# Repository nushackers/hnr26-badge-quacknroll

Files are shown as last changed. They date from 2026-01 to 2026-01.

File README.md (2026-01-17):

# hack&Roll 2026 "Quack & Roll" hardware badge

This repository contains both the hardware and firmware source files for the
Hack&Roll 2026 hardware badge.

## License

See the root directory's [LICENSE.md](./LICENSE.md) for more information on how
these materials are licensed.

## Acknowledgements

This Hack&Roll 2026 hardware badge would not have been possible without the
following people:

- **Terence** Chan Zun Mun ([@Hackin7](https://github.com/Hackin7)), for his
  invaluable knowledge and guidance in PCB design and hardware badge
  development, as well as liaising with Espressif Systems
- Lim **Yik Jin** ([@yikjin](https://github.com/yikjin)), for developing the
  hardware badge
- Park **Youngseo** ([@youngseopark05](https://github.com/youngseopark05)), for
  creating the artwork used for this hardware badge
- Koh Chan Hong, **Ravern** ([@ravern](https://github.com/ravern)), for liaising
  with Espressif Systems
- Tan Rongwen, **Daren** ([@darentanrw](https://github.com/darentanrw)), for
  liaising with Espressif Systems
- Everyone in [NUS Hackers](https://www.nushackers.org/) for making Hack&Roll
  2026 a reality!

The ESP32-C3-WROOM-02-N4 module in this hardware badge is also sponsored by
[Espressif Systems](https://www.espressif.com/), the manufacturers of the
widely-used ESP32 chips.

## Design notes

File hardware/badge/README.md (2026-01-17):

# HnR'26 hardware badge: hardware source files

This directory contains the [KiCad](https://www.kicad.org/) 9 hardware source
files for the Hack&Roll 2026 hardware badge.

## Manufacturing

We used [JLCPCB manufacturing services](https://jlcpcb.com/) for the hardware
badges. To help with component parts assignment and generating JLCPCB-compatible
files, we used the open source
[KiCAD JLCPCB tools](https://github.com/bouni/kicad-jlcpcb-tools) plugin.

## License

The hardware source files in this directory are open-sourced, licensed under
CERN-OHL-P-2.0. See [LICENSE.md](./LICENSE.md) for the full license text.

## Acknowledgements

HnR'26 hardware badge would not have been possible without the following people:

- **Terence** Chan Zun Mun ([@Hackin7](https://github.com/Hackin7)), for his
  invaluable knowledge and guidance in PCB design and hardware badge
  development, as well as liaising with Espressif Systems
- Lim **Yik Jin** ([@yikjin](https://github.com/yikjin)), for developing the
  hardware badge
- Park **Youngseo** ([@youngseopark05](https://github.com/youngseopark05)), for
  creating the artwork used for this hardware badge, and for HnR'26 in general
- **Daren** Tan Rongwen ([@darentanrw](https://github.com/darentanrw)), for
  liaising with Espressif Systems

The ESP32-C3-WROOM-02-N4 module in this hardware badge is also sponsored by
[Espressif Systems](https://www.espressif.com/), the manufacturers of the
widely-used ESP32 chips.

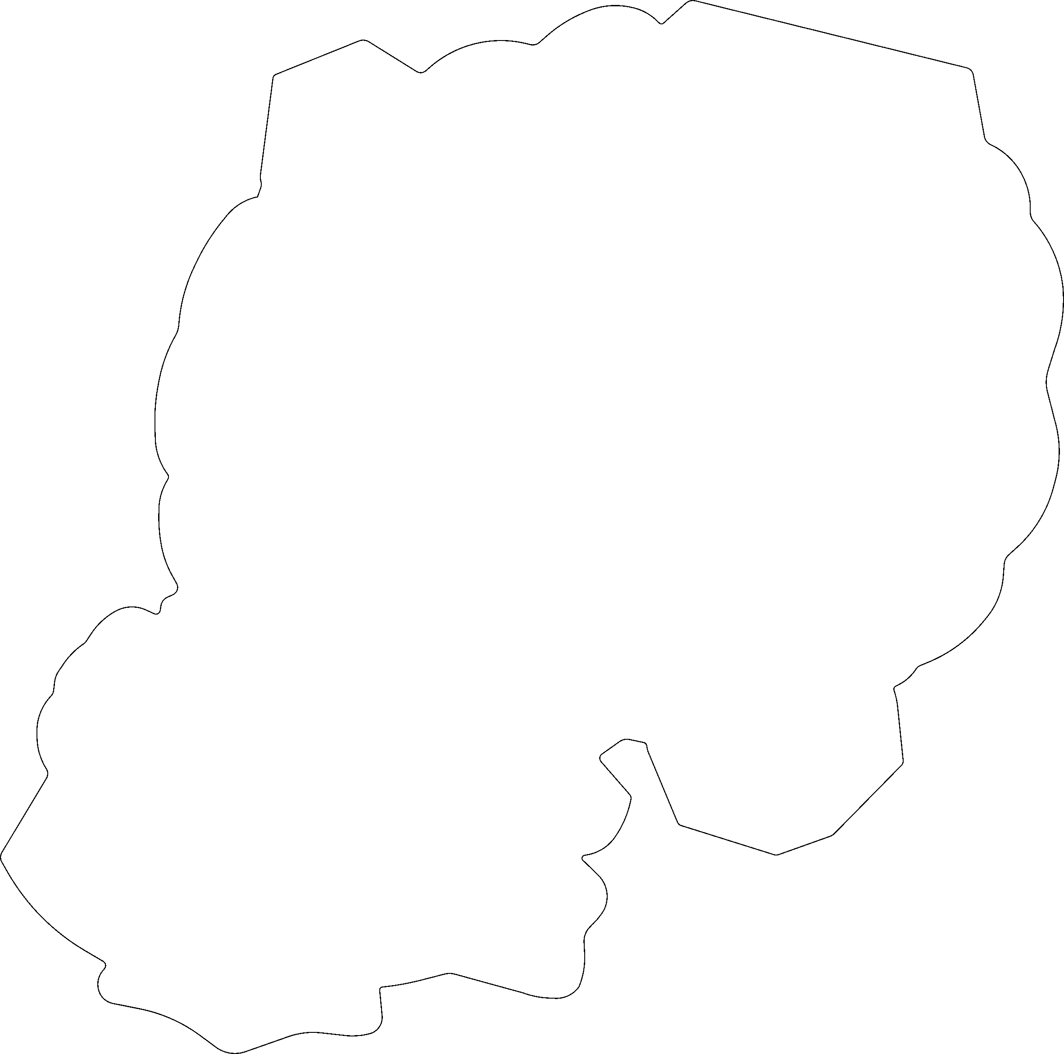
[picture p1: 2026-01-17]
art/outline.png

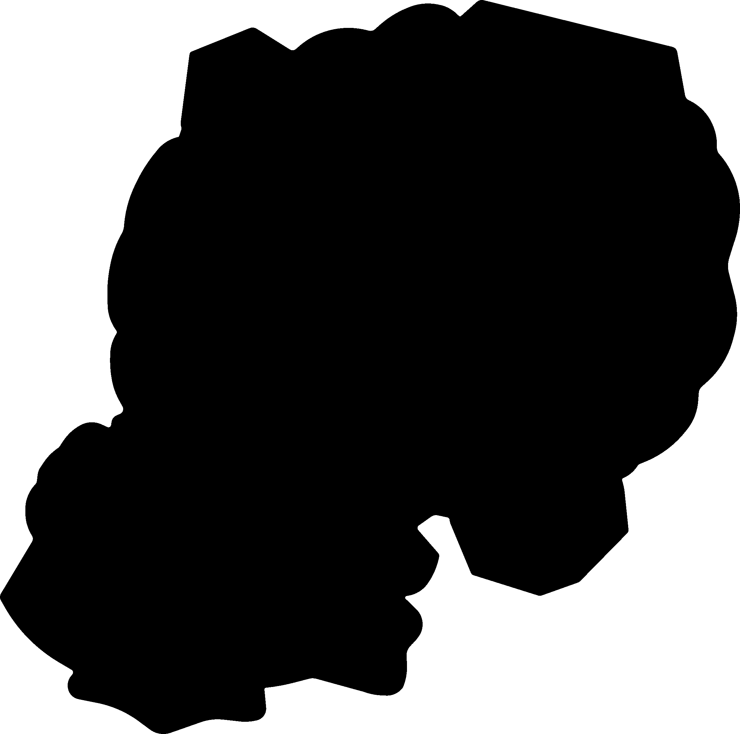
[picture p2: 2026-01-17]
art/board.png

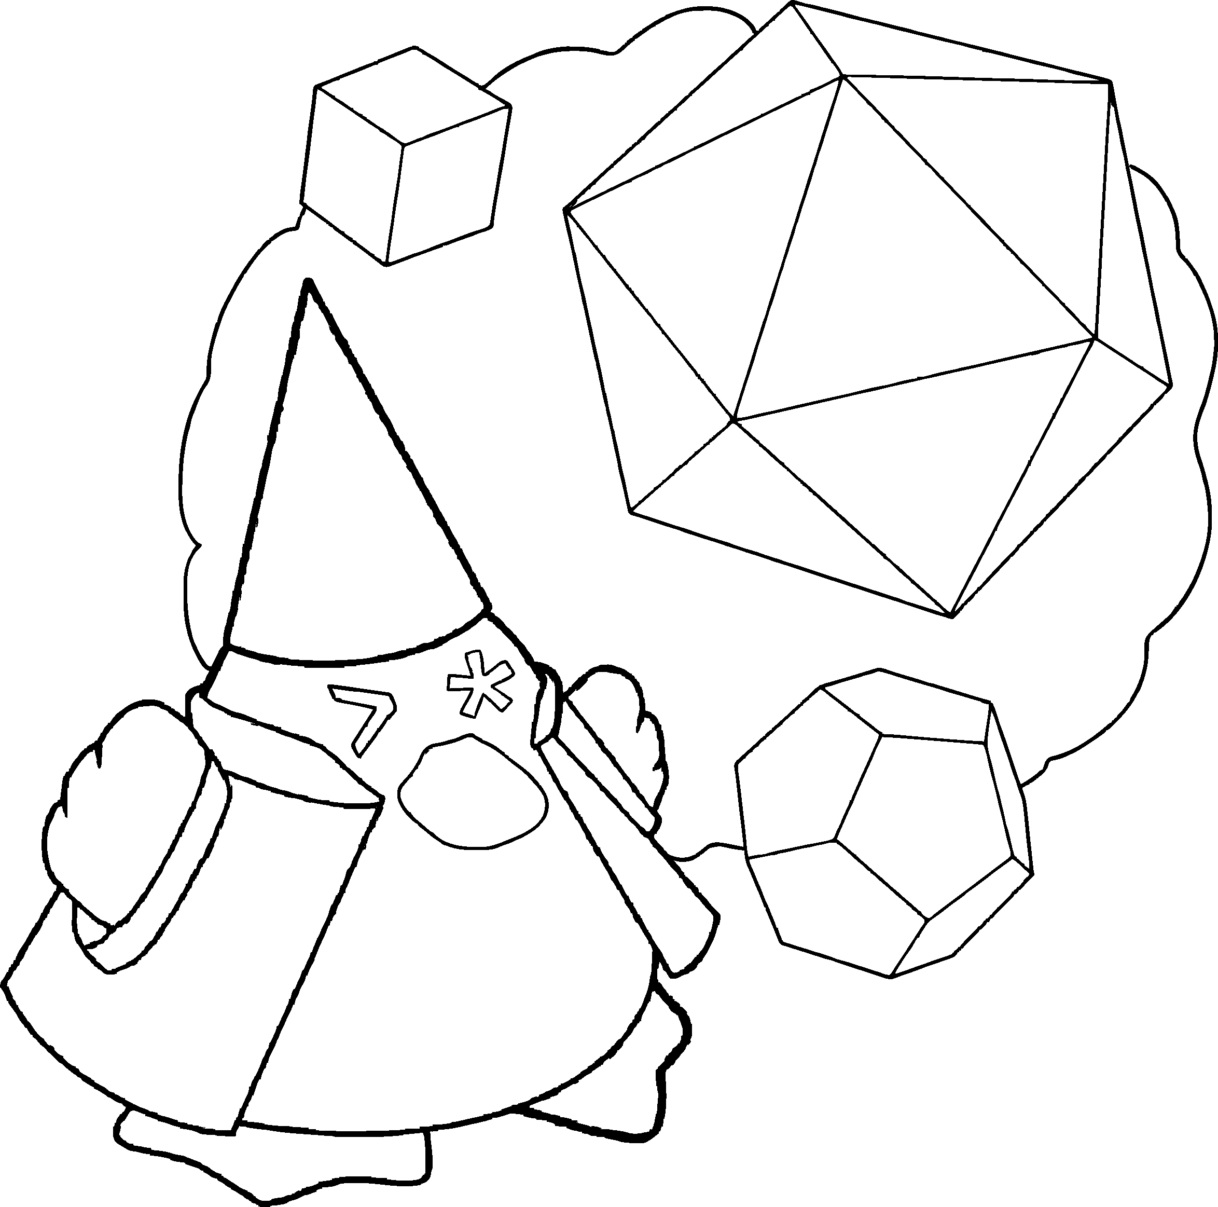
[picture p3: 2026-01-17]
art/art.png

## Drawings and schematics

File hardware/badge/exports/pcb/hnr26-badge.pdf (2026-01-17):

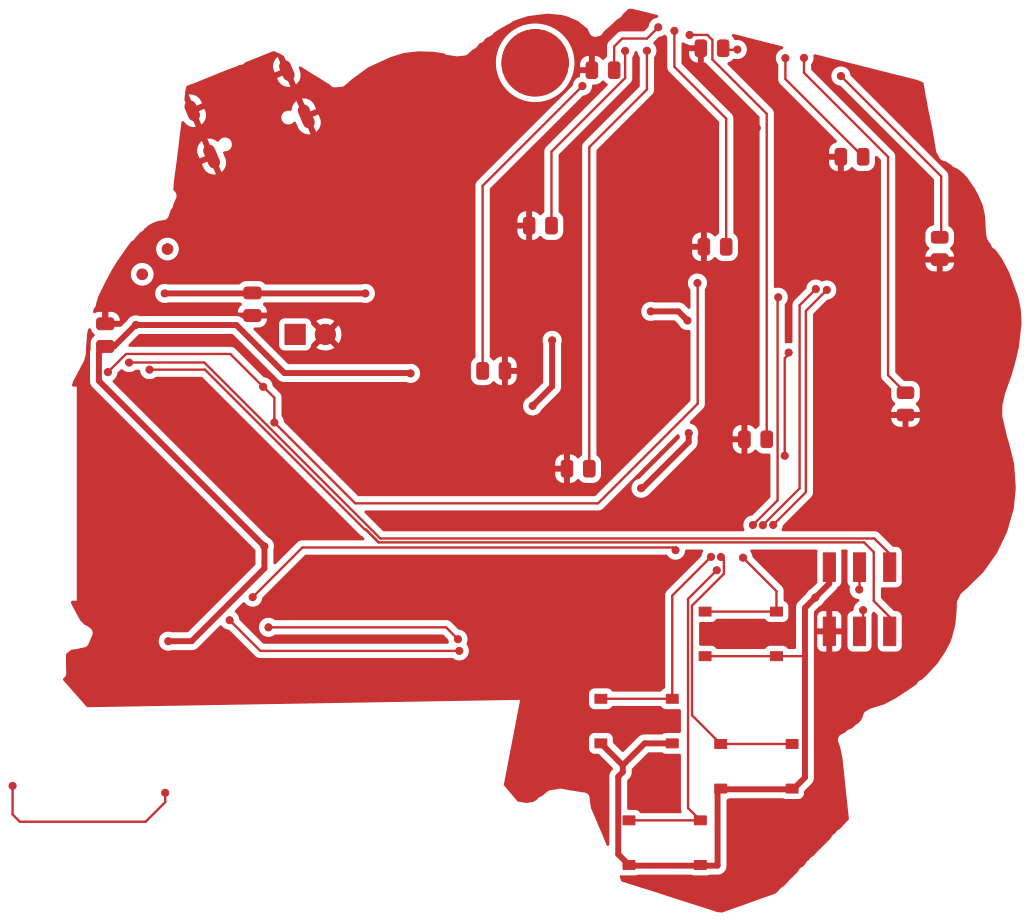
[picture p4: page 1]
D Date: 2025-12-01 KiCad; E.D.A. 9.0.7 Size: A4; Rev: 0.0.14; File: hnr26-badge.kicad_pcb Sheet: NUS; Hackers Art by @youngseopark05; Developed; by @yikjin and; @Hackin7; Licensed; under CERN-OHL-P-2.0

Id: 1/9 Title: Hack&Roll 2026 hardware badge

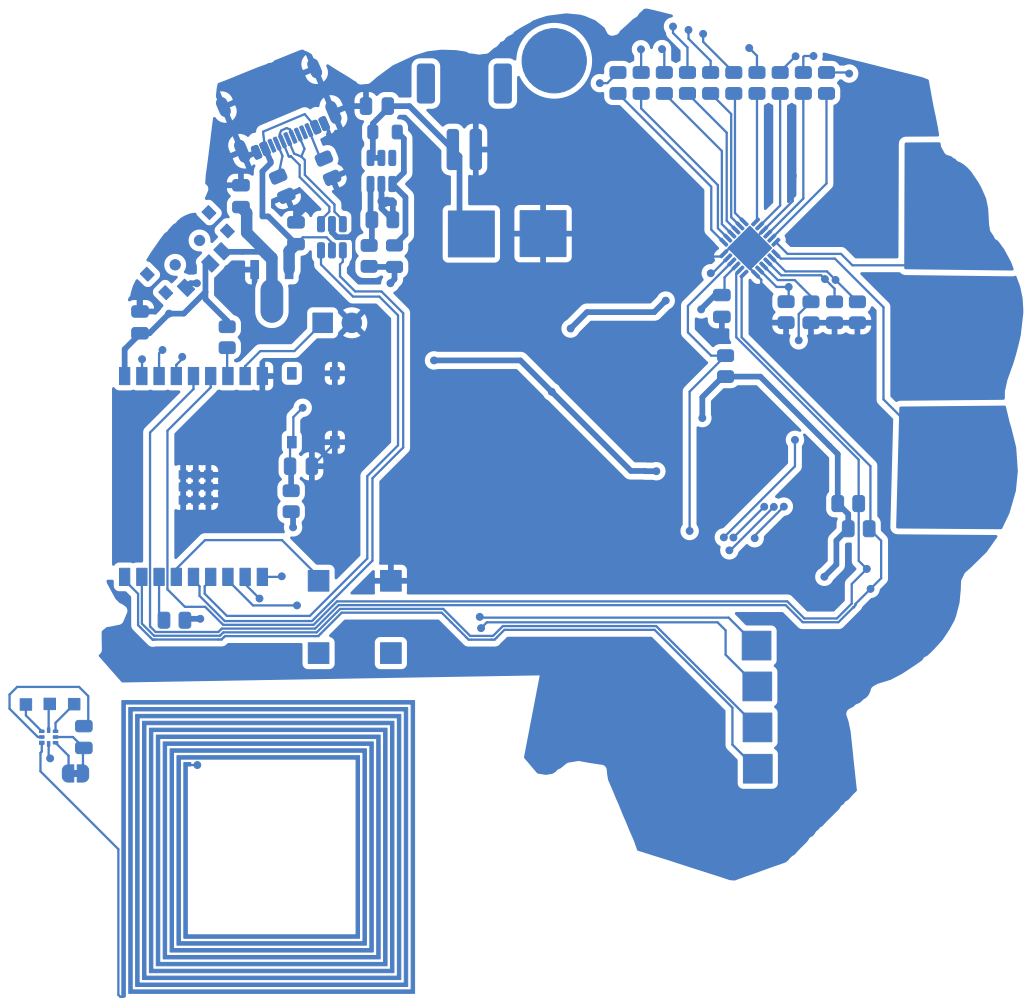
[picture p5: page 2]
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

Id: 2/9 Title: Hack&Roll 2026 hardware badge

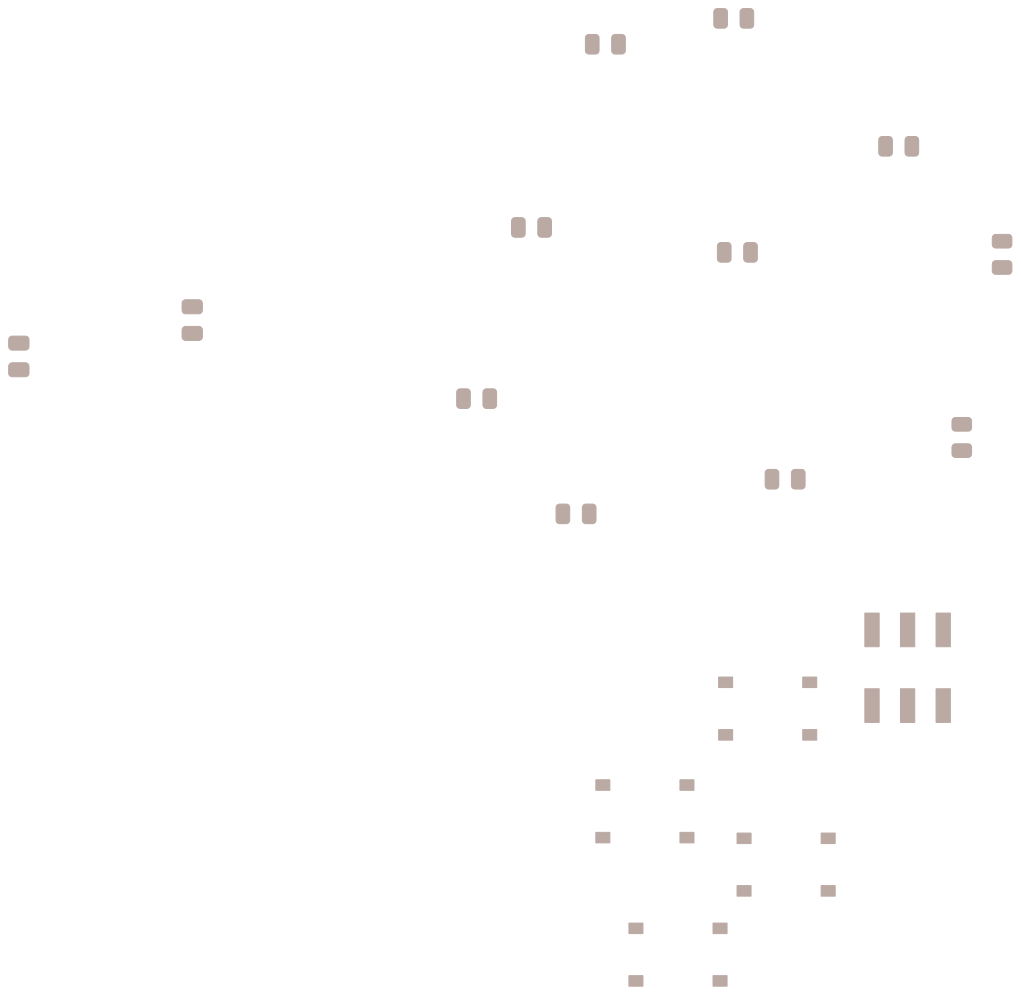
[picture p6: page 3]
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

Id: 3/9 Title: Hack&Roll 2026 hardware badge

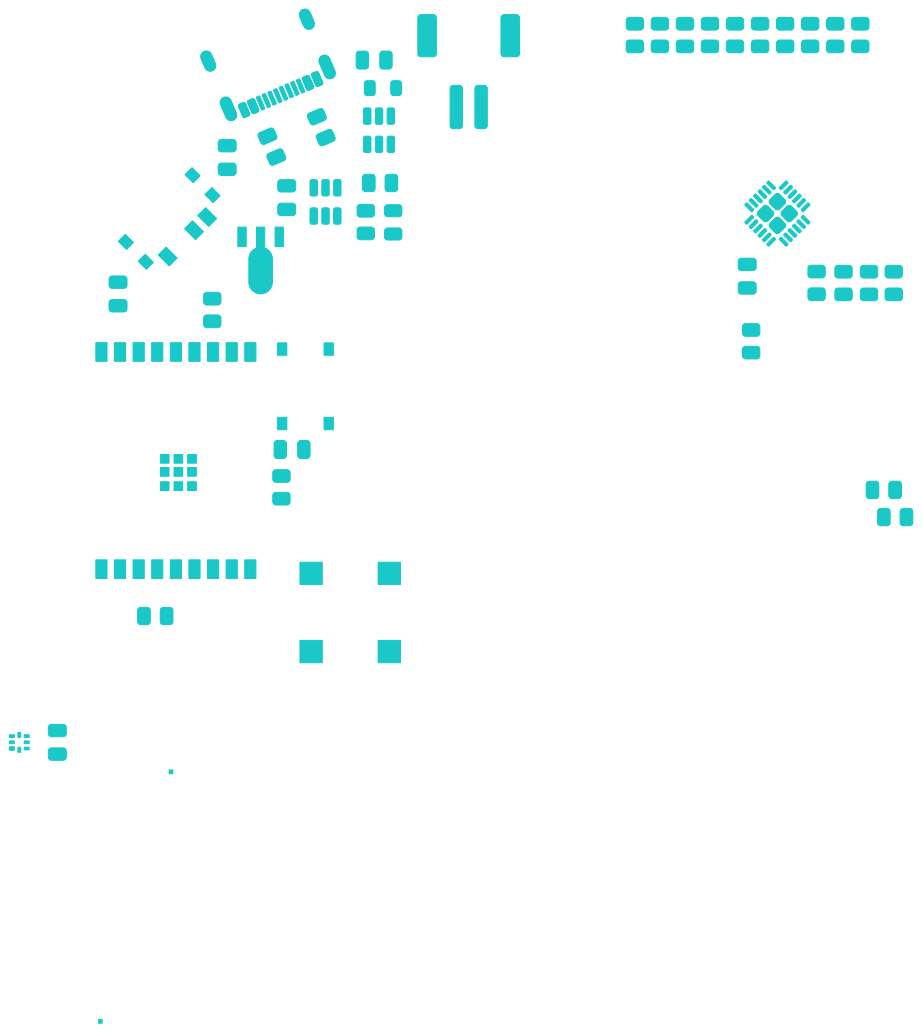
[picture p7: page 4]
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

Id: 4/9 Title: Hack&Roll 2026 hardware badge

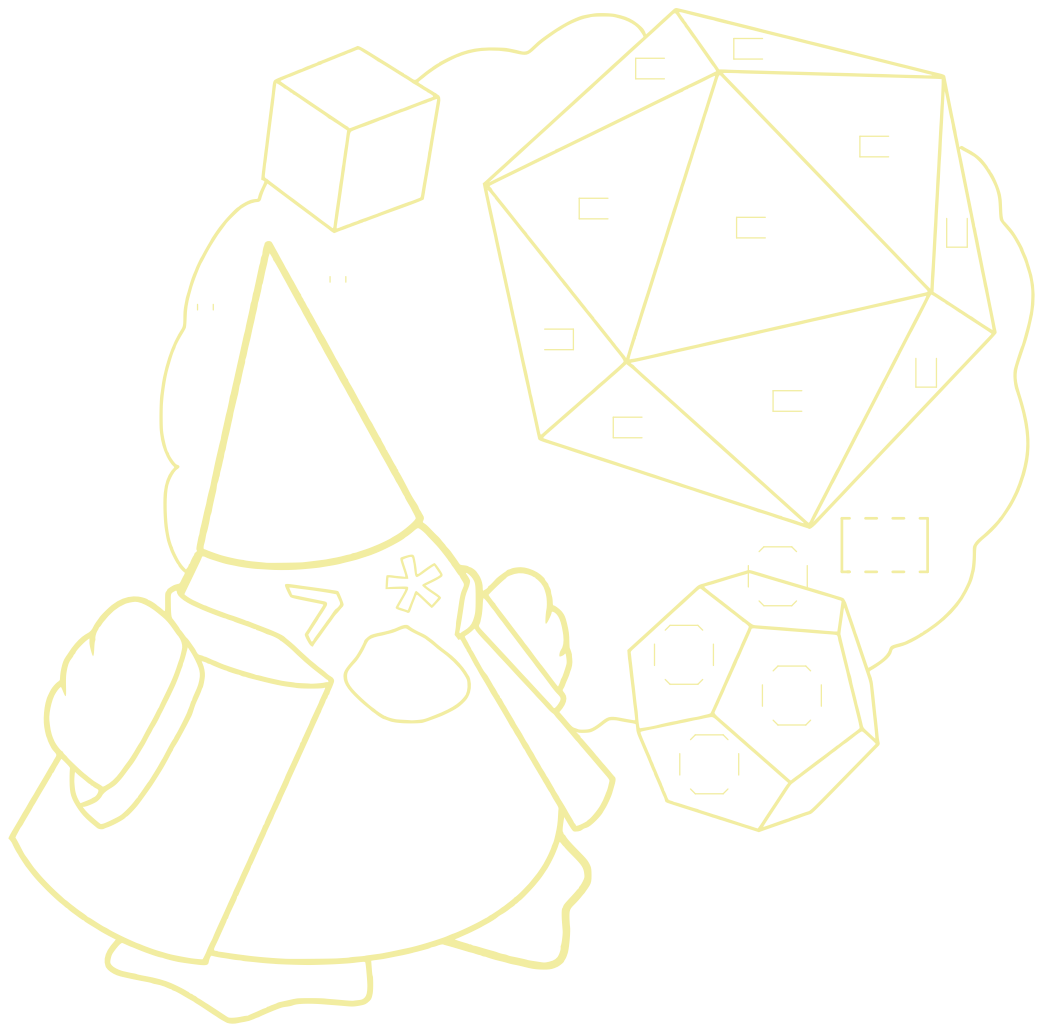
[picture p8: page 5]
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

Id: 5/9 Title: Hack&Roll 2026 hardware badge

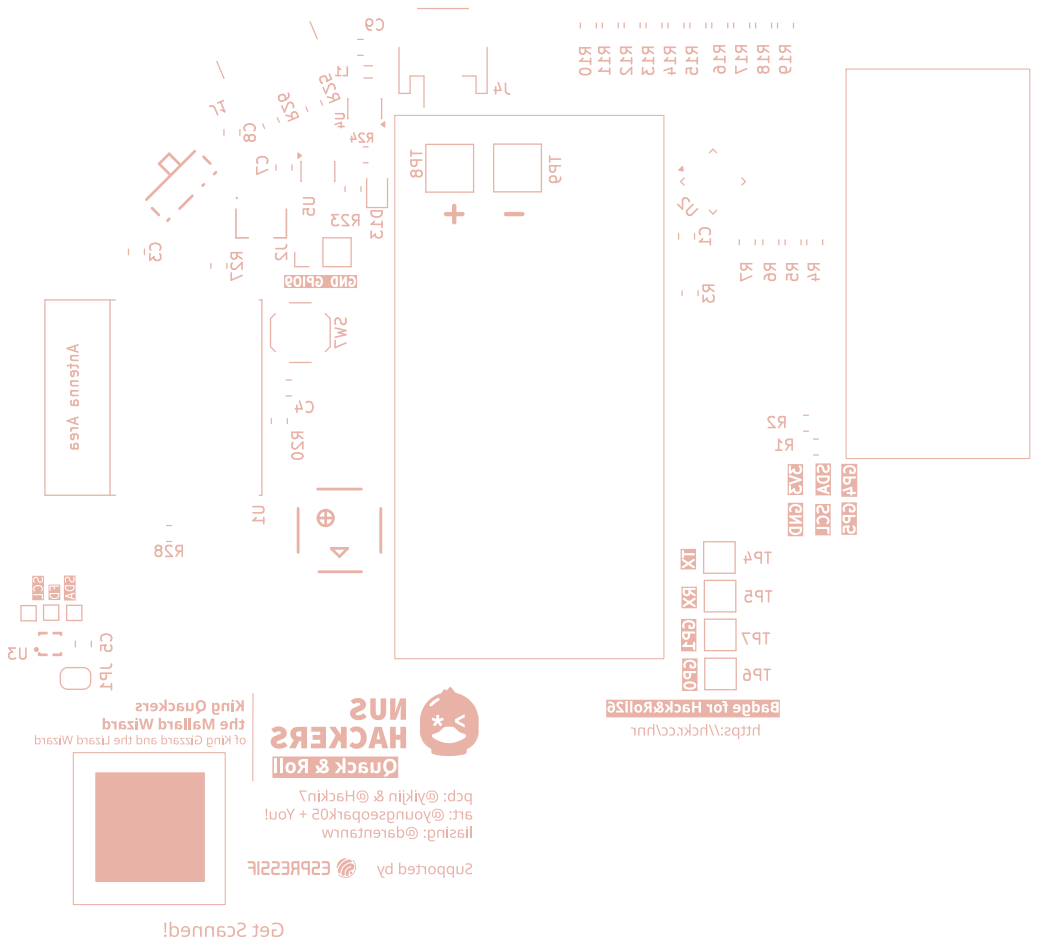
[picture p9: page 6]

Id: 6/9 Title: Hack&Roll 2026 hardware badge

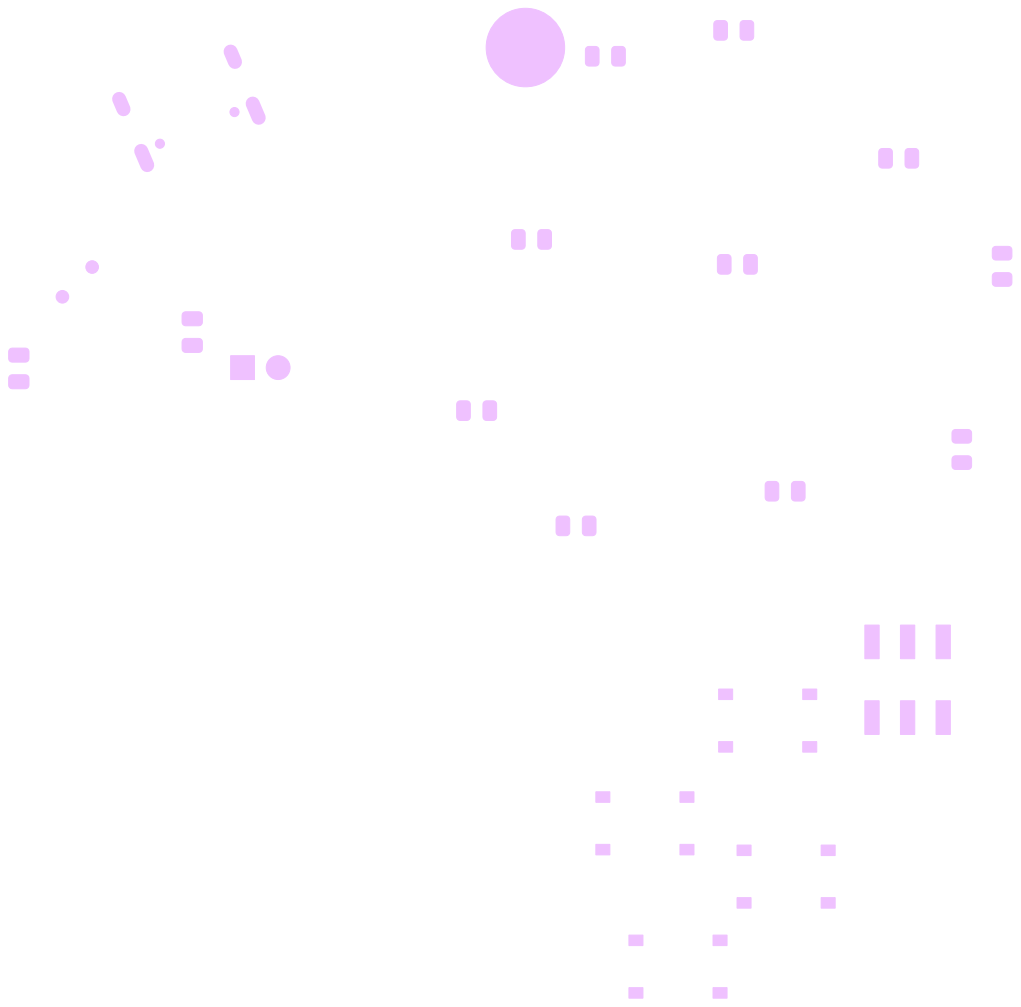
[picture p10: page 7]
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

Id: 7/9 Title: Hack&Roll 2026 hardware badge

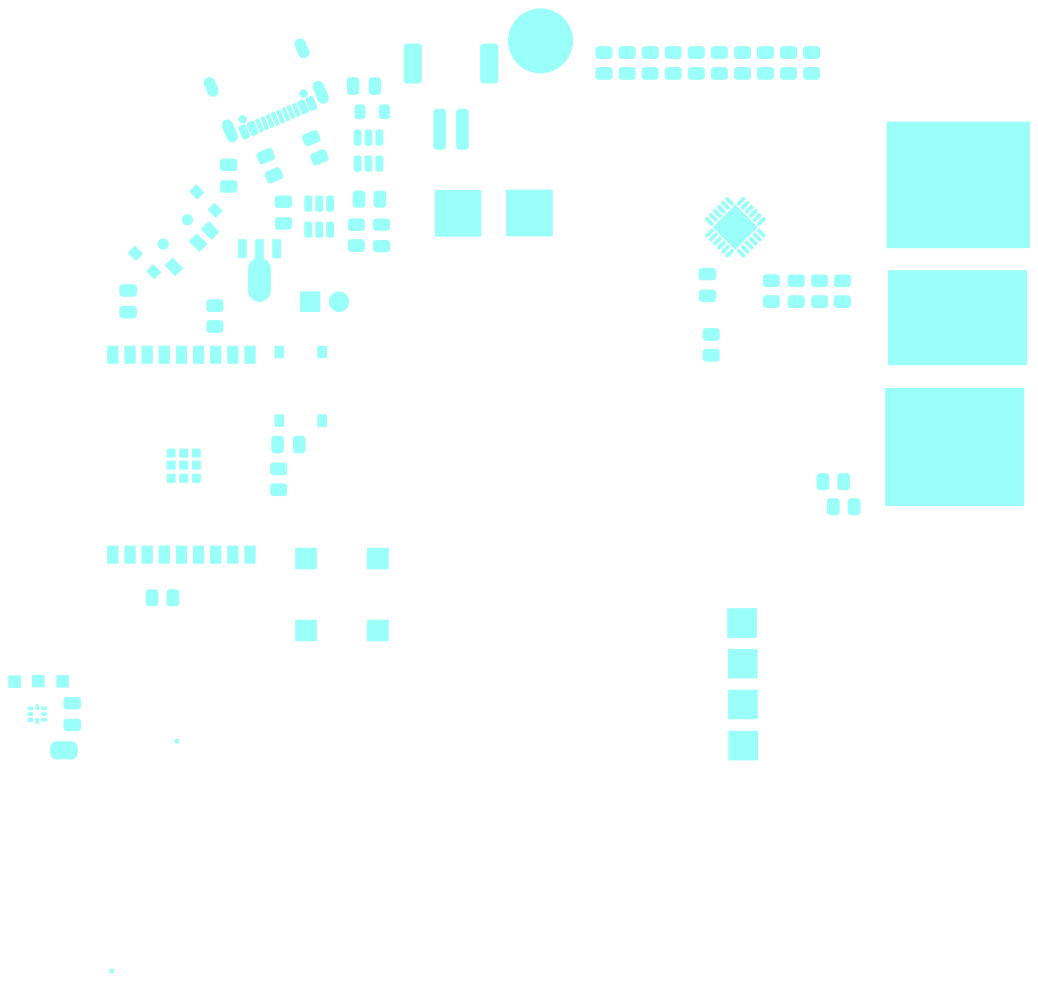
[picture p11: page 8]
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

Id: 8/9 Title: Hack&Roll 2026 hardware badge

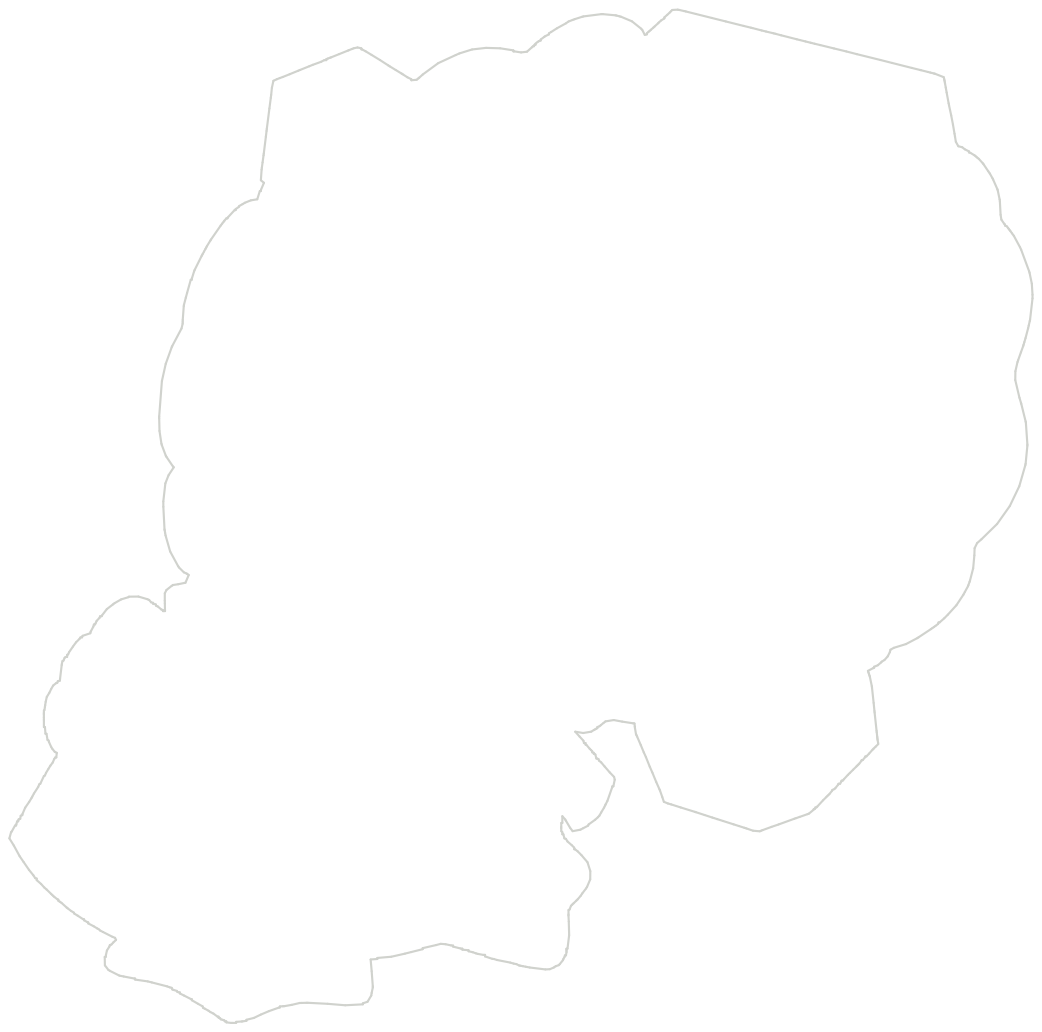
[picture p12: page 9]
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

Id: 9/9 Title: Hack&Roll 2026 hardware badge

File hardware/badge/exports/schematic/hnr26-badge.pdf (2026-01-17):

# L TP1 TestPoint JP1 SolderJumper_2_Bridged H1

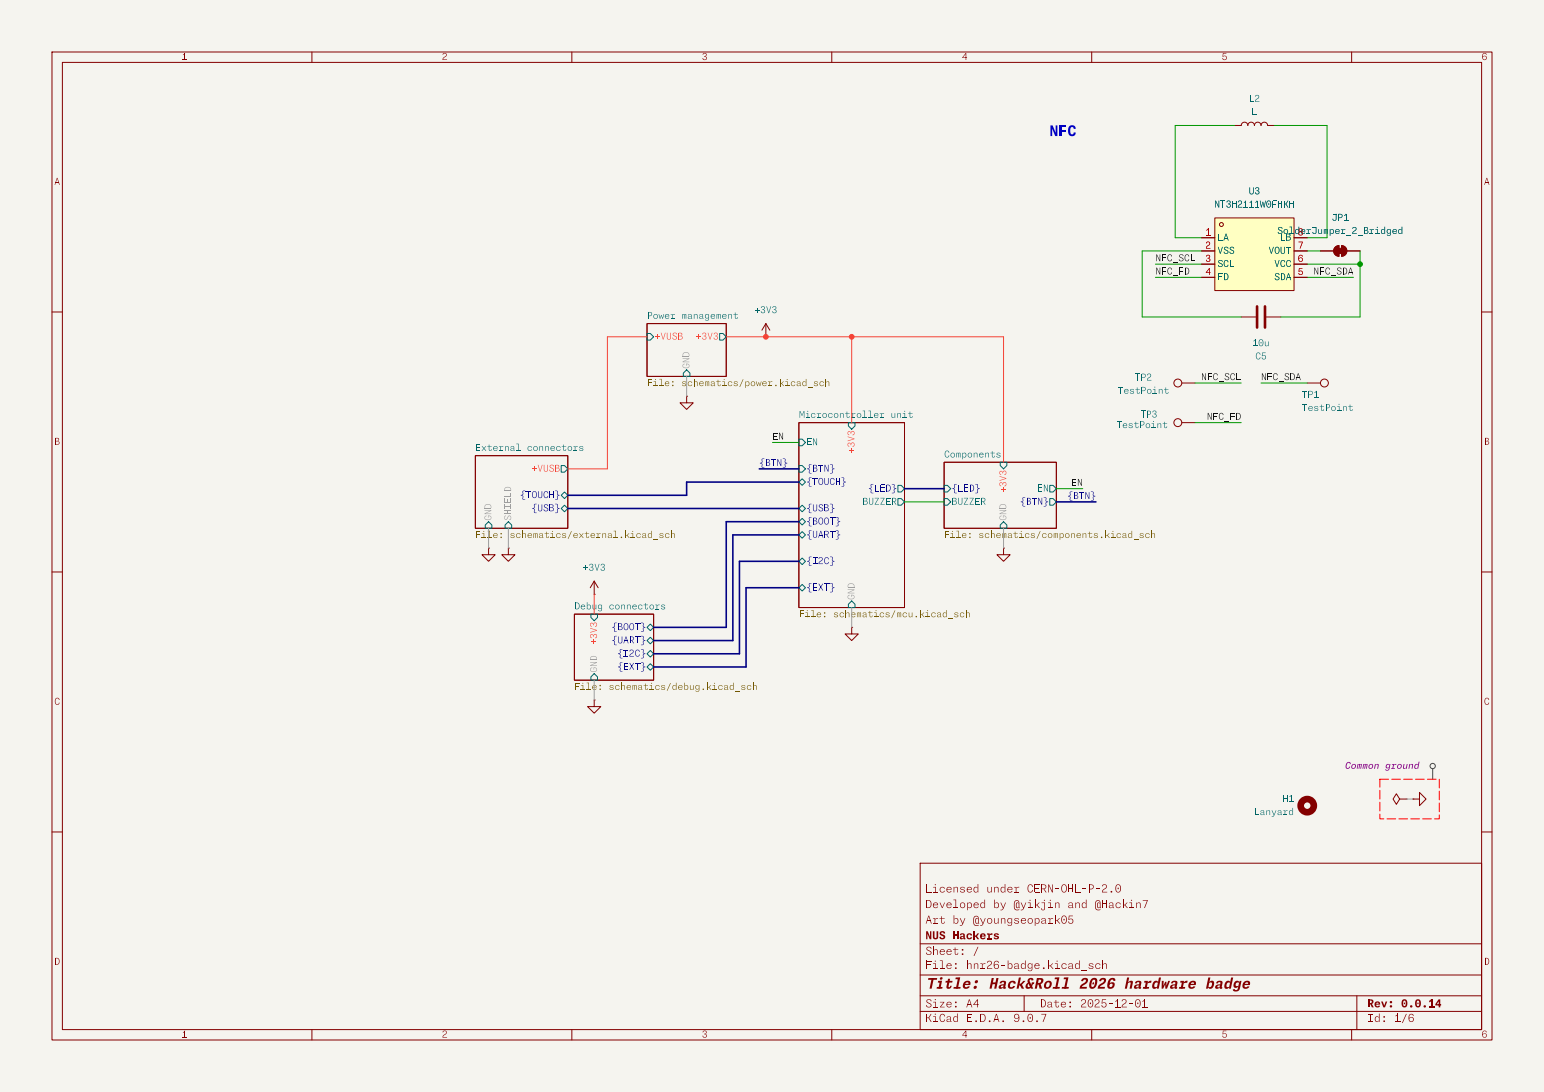
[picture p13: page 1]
D Date: 2025-12-01 KiCad; 9.0.7 Size:; Rev: 0.0.14; Id: 1/6 Title:; Hack&Roll 2026 hardware badge; File:; hnr26-badge.kicad_sch Sheet:; / NUS; Hackers Art by @youngseopark05; Developed; by @yikjin; and @Hackin7; Licensed; under CERN-OHL-P-2.0 GND ⁺³V³; {EXT}; {BOOT} {UART} {I2C}; Debug connectors File:; schematics/debug.kicad_sch +VUSB GND; SHIELD{TOUCH}; {USB} External; connectors File:; schematics/external.kicad_sch; EN GNDBUZZER; {BTN}; {LED}; Components File: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

LB 8 VOUT 7 VCC 6 SDA 5 U3 NT3H2111W0FHKH

LA 1 VSS 2 SCL 3 FD 4

LB 8 VOUT 7 VCC 6 SDA 5

# EN GND {I2C}

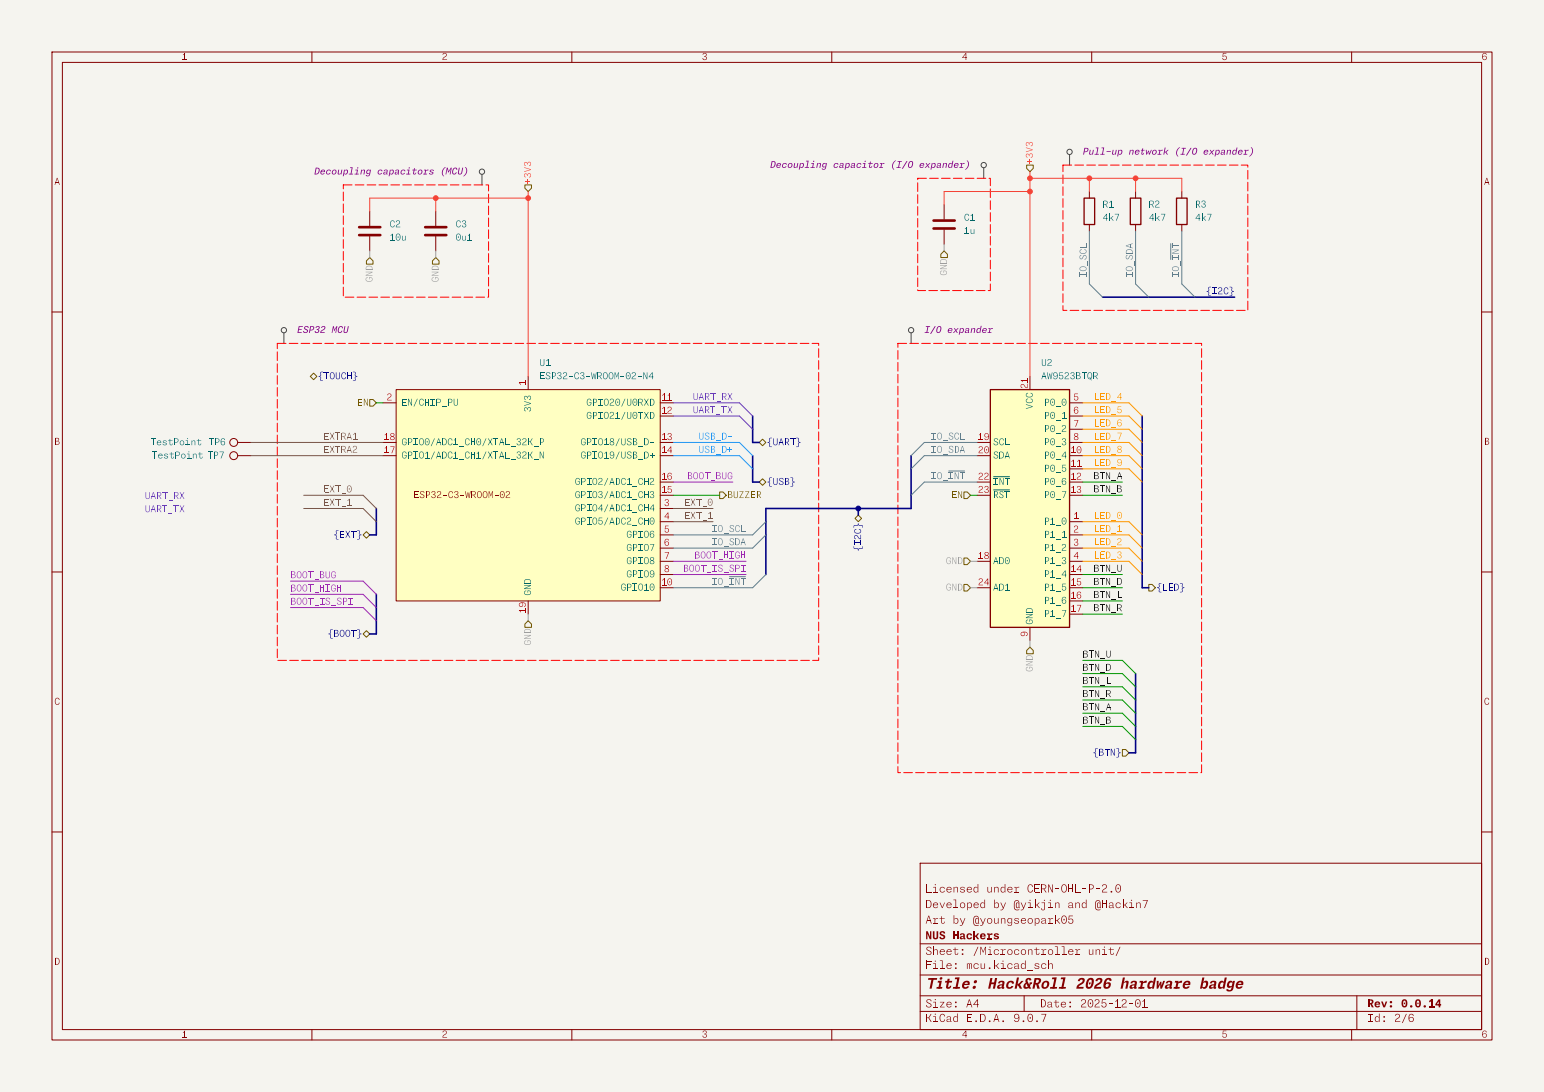
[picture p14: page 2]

1 GND 19 GPIO20/U0RXD 11 GPIO21/U0TXD 12 GPIO18/USB_D- 13 GPIO19/USB_D+ 14 GPIO2/ADC1_CH2 16 GPIO3/ADC1_CH3 15 GPIO4/ADC1_CH4 3 GPIO5/ADC2_CH0 4 GPIO6 5 GPIO7 6 GPIO8 7 GPIO9 8 GPIO10 10 U1ESP32-C3-WROOM-02-N4 TestPoint TP7 SCL 19 SDA 20 ~{INT} 22 ~{RST} 23 AD0 18 AD1 24 VCC21 GND

10k R5

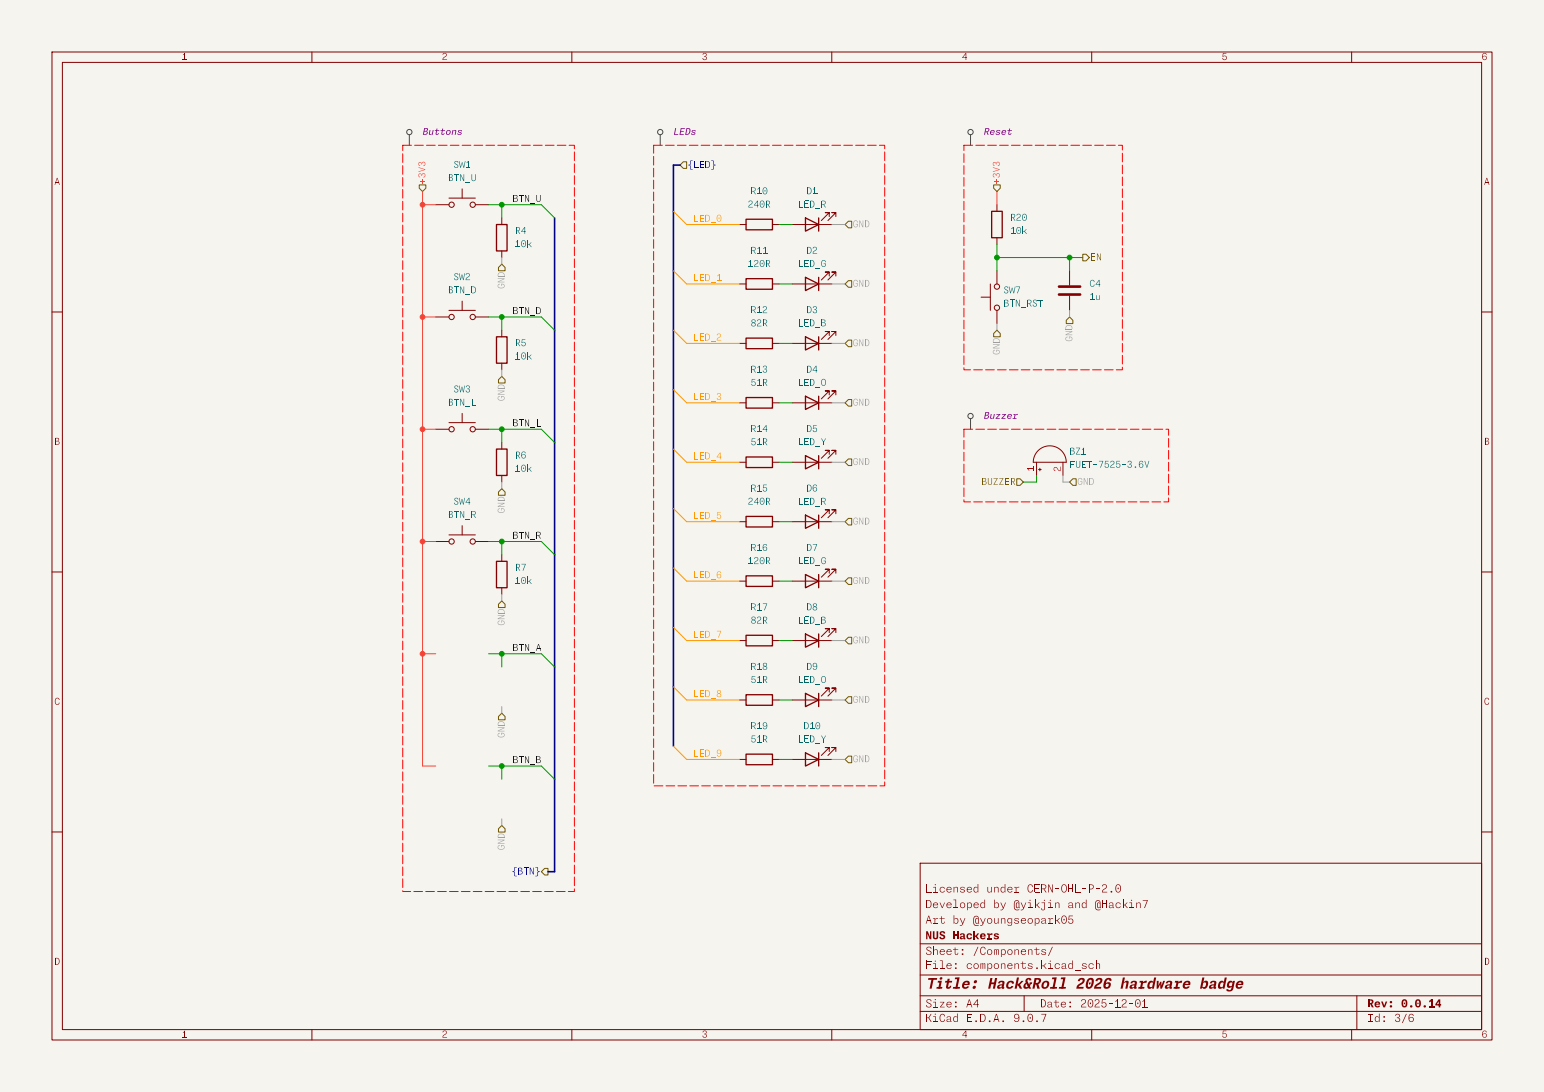
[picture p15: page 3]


D Date: 2025-12-01 KiCad; 9.0.7 Size:; Rev: 0.0.14; Id: 5/6 Title:; Hack&Roll 2026 hardware badge; File:; external.kicad_sch Sheet:; /External; connectors/ NUS; Hackers Art by @youngseopark05; Developed; by @yikjin; and @Hackin7; Licensed; under CERN-OHL-P-2.0 R26; 5k1 SHIELD S¹; GND A¹; VBUS A4 D-; B7 D+ A6 D+ B6 CC1 A5 CC2 B5 SBU1 A8 SBU2 B8; J1 USB-TYPE-C-018; 4 U5 USBLC6-2SC6-ES USB-C 2.0; Touch connector ESD protection GND; GND; GND ⁺VUSB GND SHIELD; {TOUCH}; {USB} D+D-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

D Date: 2025-12-01 KiCad; 9.0.7 Size:; Rev: 0.0.14; Id: 6/6 Title:; Hack&Roll 2026 hardware badge; File:; debug.kicad_sch Sheet:; /Debug connectors/ NUS; Hackers Art by @youngseopark05; Developed; by @yikjin; and @Hackin7; Licensed; under CERN-OHL-P-2.0; TP5 TestPoint 1; J2BOOT R27; TP4 TestPoint Boot connector; SAO connector; UART connector; External; connector +3V3 GND; {EXT}; {BOOT}; {EXT} GND; GND; {UART}; BOOT_HIGH; EXT_0 BOOT_HIGH; BOOT_BUG; BOOT_IS_SPI; IO_SCL; EXT_1; IO_SDA; EXT_0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

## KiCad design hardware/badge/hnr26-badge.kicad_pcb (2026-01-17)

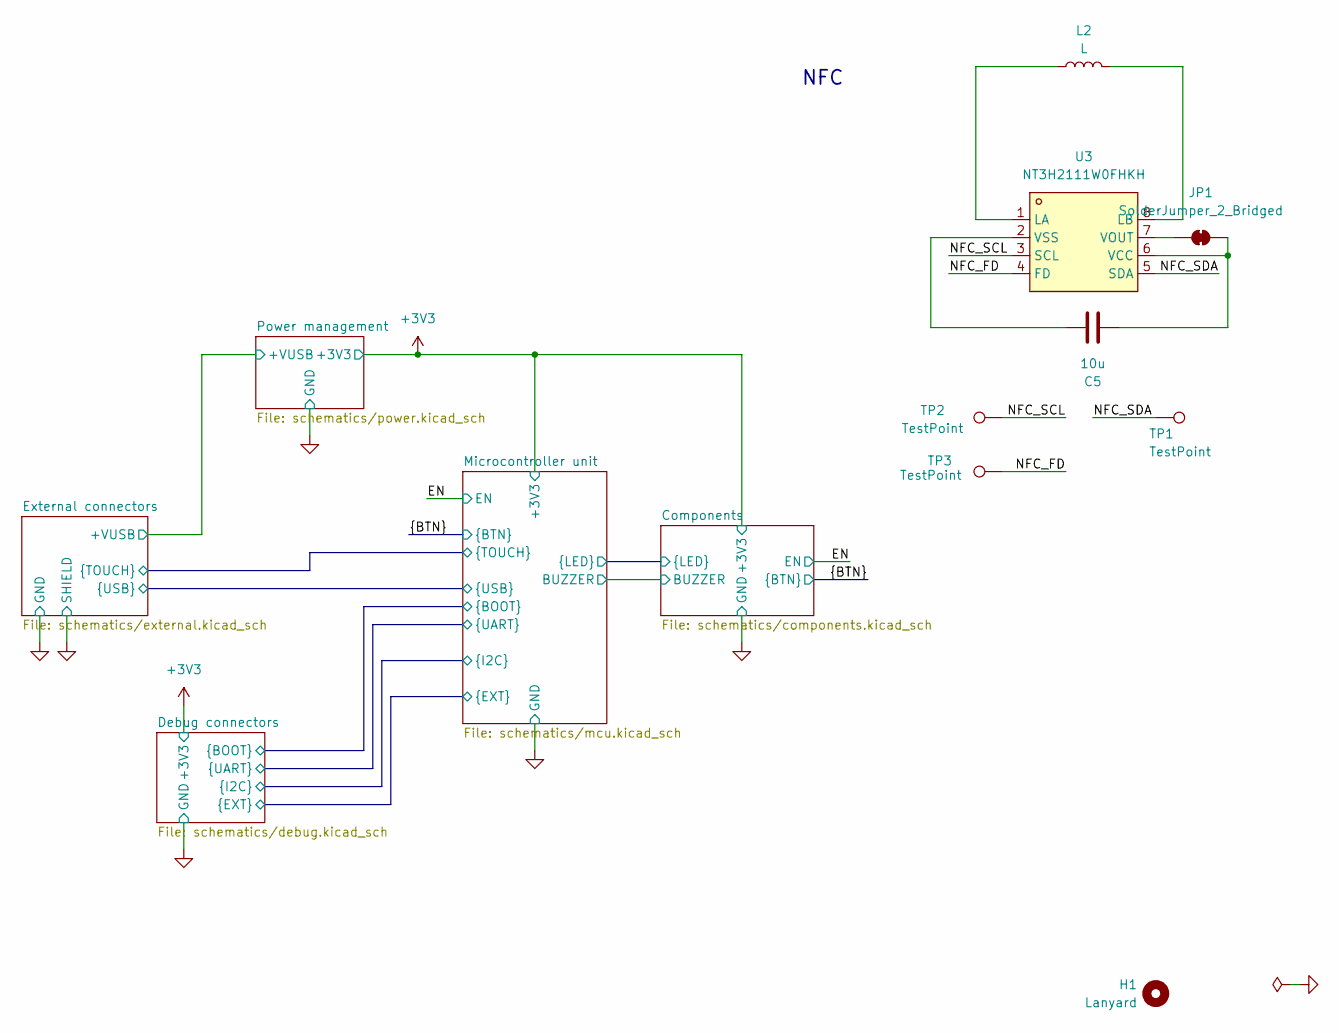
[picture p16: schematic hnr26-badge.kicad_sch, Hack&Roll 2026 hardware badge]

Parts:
C5: 10u; C_0805_2012Metric; LCSC Part # C19103847
H1: Lanyard; MountingHole_3.2mm_M3_DIN965_Pad
JP1: SolderJumper_2_Bridged; SolderJumper-2_P1.3mm_Bridged_RoundedPad1.0x1.5mm
L2: L; NFC_COIL
TP1, TP2, TP3: TestPoint; TestPoint_Pad_1.0x1.0mm
U3: NT3H2111W0FHKH; XQFN-8_L1.6-W1.6-P0.50-BL_NT3H2111W0FHKH; LCSC Part C710403

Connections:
/NFC_FD: TP3.1, U3.4 (FD)
/NFC_SCL: TP2.1, U3.3 (SCL)
/NFC_SDA: TP1.1, U3.5 (SDA)
unnamed: C5.2, JP1.1 (A), U3.6 (VCC)
unnamed: JP1.2 (B), U3.7 (VOUT)
unnamed: L2.1, U3.1 (LA)
unnamed: L2.2, U3.8 (LB)
unnamed: C5.1, U3.2 (VSS)

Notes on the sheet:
NFC

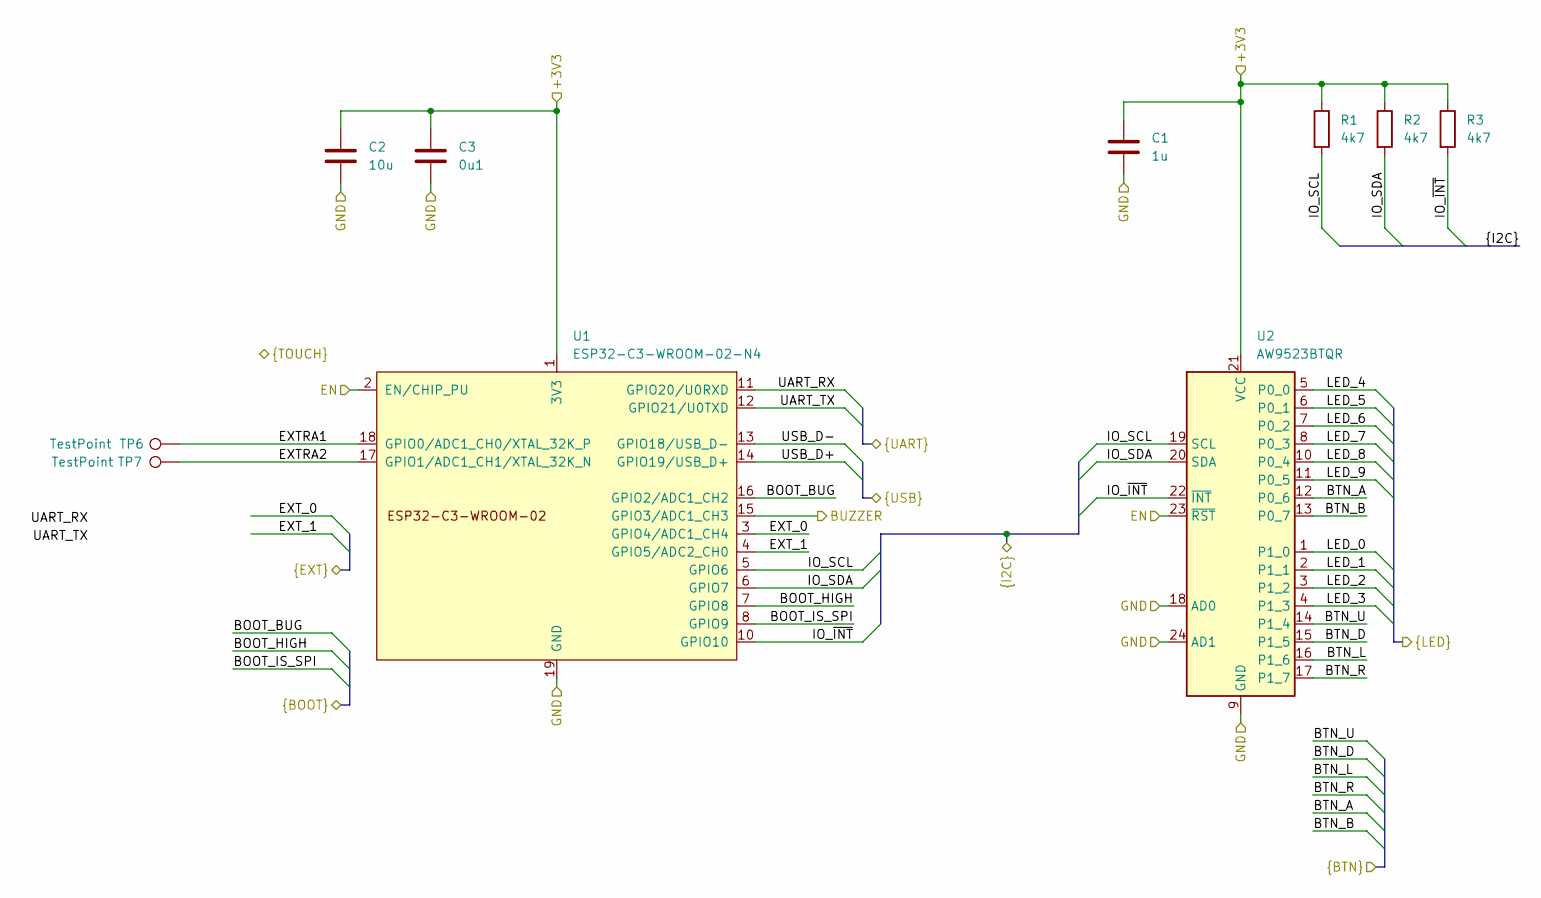
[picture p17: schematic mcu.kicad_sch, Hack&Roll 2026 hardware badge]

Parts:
C1: 1u; C_0805_2012Metric; LCSC Part # C344171
C2: 10u; C_0805_2012Metric; LCSC Part # C19103847
C3: 0u1; C_0805_2012Metric; LCSC Part # C5137467
R1, R2, R3: 4k7; R_0805_2012Metric; LCSC Part # C2907326
TP6, TP7: TestPoint; TestPoint_Pad_2.5x2.5mm
U1: ESP32-C3-WROOM-02-N4; ESP32-C3-WROOM-02; LCSC Part # C2934560
U2: AW9523BTQR; QFN-24-1EP_4x4mm_P0.5mm_EP2.7x2.7mm; LCSC Part # C148077

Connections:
+3V3: C1.1, C2.1, C3.1, R1.1, R2.1, R3.1, U1.1 (3V3), U2.21 (VCC); also elsewhere on the board
/BTN_A: U2.12 (P0_6)
/BTN_B: U2.13 (P0_7)
/BTN_D: U2.15 (P1_5); also elsewhere on the board
/BTN_L: U2.16 (P1_6); also elsewhere on the board
/BTN_R: U2.17 (P1_7); also elsewhere on the board
/BTN_U: U2.14 (P1_4); also elsewhere on the board
/Components/BUZZER: U1.15 (GPIO3/ADC1_CH3); also elsewhere on the board
/Components/LED_0: U2.1 (P1_0); also elsewhere on the board
/Components/LED_1: U2.2 (P1_1); also elsewhere on the board
/Components/LED_2: U2.3 (P1_2); also elsewhere on the board
/Components/LED_3: U2.4 (P1_3); also elsewhere on the board
/Components/LED_4: U2.5 (P0_0); also elsewhere on the board
/Components/LED_5: U2.6 (P0_1); also elsewhere on the board
/Components/LED_6: U2.7 (P0_2); also elsewhere on the board
/Components/LED_7: U2.8 (P0_3); also elsewhere on the board
/Components/LED_8: U2.10 (P0_4); also elsewhere on the board
/Components/LED_9: U2.11 (P0_5); also elsewhere on the board
/Debug connectors/BOOT_BUG: U1.16 (GPIO2/ADC1_CH2); also elsewhere on the board
/Debug connectors/BOOT_HIGH: U1.7 (GPIO8); also elsewhere on the board
/Debug connectors/BOOT_IS_SPI: U1.8 (GPIO9); also elsewhere on the board
/Debug connectors/EXT_0: U1.3 (GPIO4/ADC1_CH4); also elsewhere on the board
/Debug connectors/EXT_1: U1.4 (GPIO5/ADC2_CH0); also elsewhere on the board
/Debug connectors/UART_RX: U1.11 (GPIO20/U0RXD); also elsewhere on the board
/Debug connectors/UART_TX: U1.12 (GPIO21/U0TXD); also elsewhere on the board
/EN: U1.2 (EN/CHIP_PU), U2.23 (~RST); also elsewhere on the board
/External connectors/USB_D+: U1.14 (GPIO19/USB_D+); also elsewhere on the board
/External connectors/USB_D-: U1.13 (GPIO18/USB_D-); also elsewhere on the board
/Microcontroller unit/EXTRA1: TP6.1, U1.18 (GPIO0/ADC1_CH0/XTAL_32K_P)
/Microcontroller unit/EXTRA2: TP7.1, U1.17 (GPIO1/ADC1_CH1/XTAL_32K_N)
/Microcontroller unit/IO_SCL: R1.2, U1.5 (GPIO6), U2.19 (SCL); also elsewhere on the board
/Microcontroller unit/IO_SDA: R2.2, U1.6 (GPIO7), U2.20 (SDA); also elsewhere on the board
/Microcontroller unit/IO_~INT: R3.2, U1.10 (GPIO10), U2.22 (~INT)
GND: C1.2, C2.2, C3.2, U1.9 (GND), U1.19 (GND), U2.9 (GND), U2.18 (AD0), U2.24 (AD1), U2.25 (GND); also elsewhere on the board

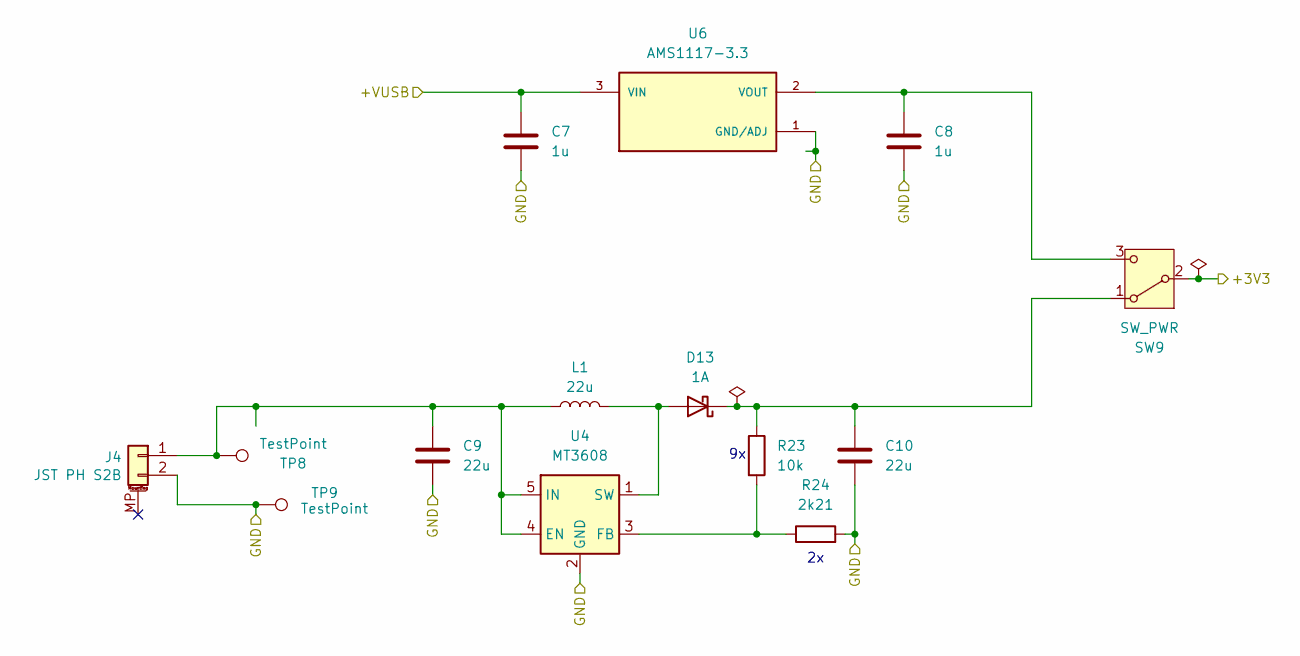
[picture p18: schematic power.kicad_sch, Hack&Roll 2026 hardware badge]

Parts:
C7, C8: 1u; C_0805_2012Metric; LCSC Part # C344171
C9, C10: 22u; C_0805_2012Metric; LCSC Part # C5674
D13: 1A; D_0805_2012Metric; LCSC Part # C143773
J4: JST PH S2B; JST_PH_S2B-PH-SM4-TB_1x02-1MP_P2.00mm_Horizontal; LCSC C505023
L1: 22u; L_0805_2012Metric; LCSC Part # C32375
R23: 10k; R_0805_2012Metric; LCSC Part # C2930231
R24: 2k21; R_0805_2012Metric; LCSC Part # C5121533
SW9: SW_PWR; SW-SMD_SK-01A-H1.5; LCSC Part # C778186
TP8, TP9: TestPoint; TestPoint_Pad_4.0x4.0mm
U4: MT3608; SOT-23-6; LCSC Part # C84817
U6: AMS1117-3.3; SOT-89-3_L4.5-W2.5-P1.50-LS4.2-BR; PARTREV N/A

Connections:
+3V3: SW9.2 (B); also elsewhere on the board
/External connectors/+VUSB: C7.1, U6.3 (VIN); also elsewhere on the board
GND: C7.2, C8.2, C9.2, C10.2, J4.2, R24.2, TP9.1, U4.2 (GND), U6.1 (GND/ADJ); also elsewhere on the board
unnamed: D13.2 (A), L1.2, U4.1 (SW)
unnamed: C10.1, D13.1 (K), R23.1, SW9.1 (A)
unnamed: C9.1, J4.1, L1.1, TP8.1, U4.4 (EN), U4.5 (IN)
unnamed: C8.1, SW9.3 (C), U6.2 (VOUT)
unnamed: R23.2, R24.1, U4.3 (FB)

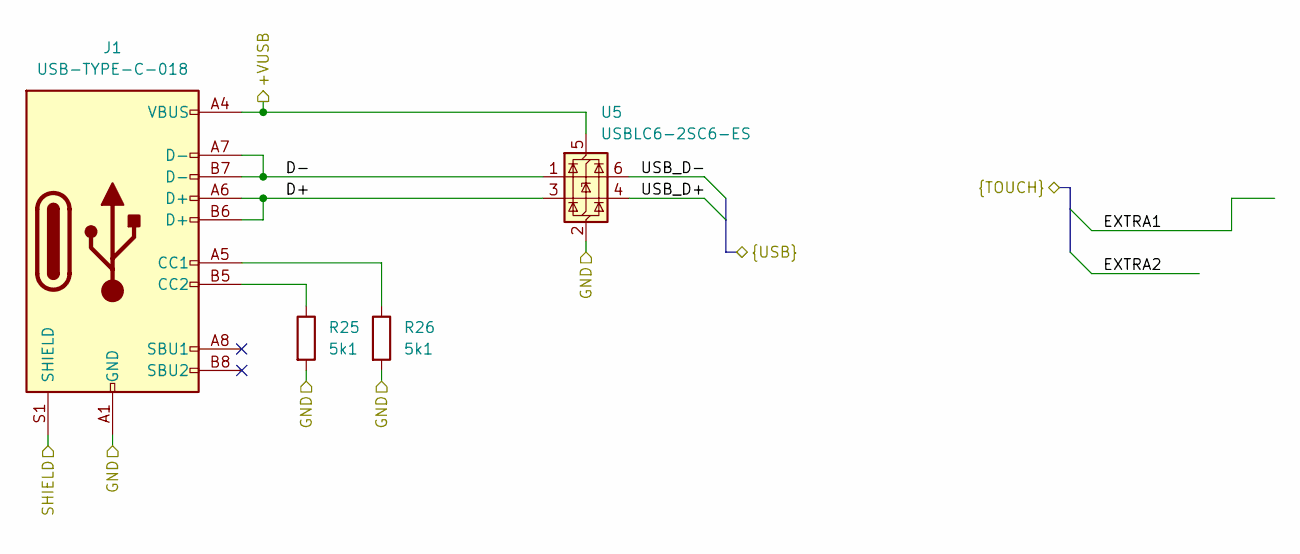
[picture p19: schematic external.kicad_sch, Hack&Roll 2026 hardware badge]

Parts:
J1: USB-TYPE-C-018; USB_C_Receptacle_GCT_USB4105-xx-A_16P_TopMnt_Horizontal; LCSC Part # C2927038
R25, R26: 5k1; R_0805_2012Metric; LCSC Part # C22356678
U5: USBLC6-2SC6-ES; SOT-23-6; LCSC Part # C5180249

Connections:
/External connectors/+VUSB: J1.A4 (VBUS), J1.A9 (VBUS), J1.B4 (VBUS), J1.B9 (VBUS), U5.5 (VBUS); also elsewhere on the board
/External connectors/D+: J1.A6 (D+), J1.B6 (D+), U5.3 (I/O2)
/External connectors/D-: J1.A7 (D-), J1.B7 (D-), U5.1 (I/O1)
/External connectors/USB_D+: U5.4 (I/O2); also elsewhere on the board
/External connectors/USB_D-: U5.6 (I/O1); also elsewhere on the board
GND: J1.A1 (GND), J1.A12 (GND), J1.B1 (GND), J1.B12 (GND), J1.S1 (SHIELD), R25.2, R26.2, U5.2 (GND); also elsewhere on the board
unnamed: J1.A5 (CC1), R26.1
unnamed: J1.B5 (CC2), R25.1

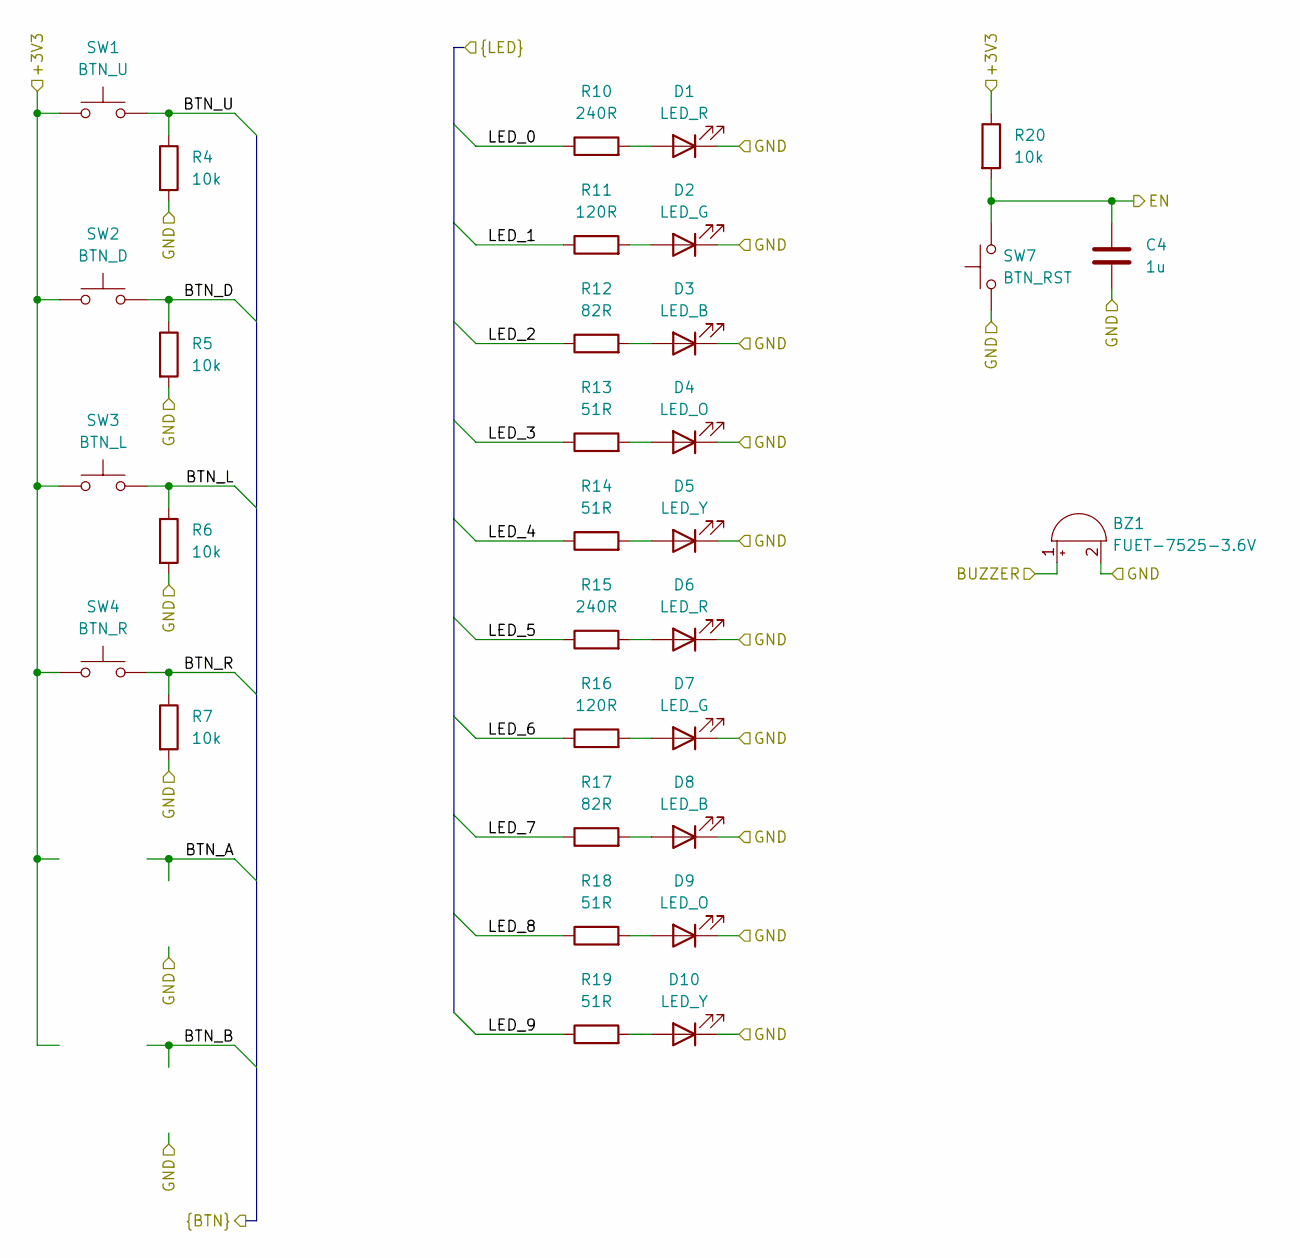
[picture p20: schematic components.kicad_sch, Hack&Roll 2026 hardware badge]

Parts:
BZ1: FUET-7525-3.6V; Buzzer-SMD_4P-L7.5-W7.5-BR; LCSC Part # C417427
C4: 1u; C_0805_2012Metric; LCSC Part # C344171
D1, D6: LED_R; LED_0805_2012Metric; LCSC Part # C7496834
D2, D7: LED_G; LED_0805_2012Metric; LCSC Part # C7496832
D3, D8: LED_B; LED_0805_2012Metric; LCSC Part # C7496833
D4, D9: LED_O; LED_0805_2012Metric; LCSC Part # C965813
D5, D10: LED_Y; LED_0805_2012Metric; LCSC Part # C965814
R4, R5, R6, R7, R20: 10k; R_0805_2012Metric; LCSC Part # C2930231
R10, R15: 240R; R_0805_2012Metric; LCSC Part # C25296
R11, R16: 120R; R_0805_2012Metric; LCSC Part # C3013232
R12, R17: 82R; R_0805_2012Metric; LCSC Part # C2907344
R13, R14, R18, R19: 51R; R_0805_2012Metric; LCSC Part # C2907334
SW1: BTN_U; SW_Push_1P1T_XKB_TS-1187A; LCSC Part # C2888877
SW2: BTN_D; SW_Push_1P1T_XKB_TS-1187A; LCSC Part # C2888877
SW3: BTN_L; SW_Push_1P1T_XKB_TS-1187A; LCSC Part # C2888877
SW4: BTN_R; SW_Push_1P1T_XKB_TS-1187A; LCSC Part # C2888877
SW7: BTN_RST; SW_Push_1P1T_XKB_TS-1187A; LCSC Part # C2888877

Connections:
+3V3: R20.1, SW1.1, SW2.1, SW3.1, SW4.1; also elsewhere on the board
/BTN_D: R5.1, SW2.2; also elsewhere on the board
/BTN_L: R6.1, SW3.2; also elsewhere on the board
/BTN_R: R7.1, SW4.2; also elsewhere on the board
/BTN_U: R4.1, SW1.2; also elsewhere on the board
/Components/BUZZER: BZ1.1 (+); also elsewhere on the board
/Components/LED_0: R10.1; also elsewhere on the board
/Components/LED_1: R11.1; also elsewhere on the board
/Components/LED_2: R12.1; also elsewhere on the board
/Components/LED_3: R13.1; also elsewhere on the board
/Components/LED_4: R14.1; also elsewhere on the board
/Components/LED_5: R15.1; also elsewhere on the board
/Components/LED_6: R16.1; also elsewhere on the board
/Components/LED_7: R17.1; also elsewhere on the board
/Components/LED_8: R18.1; also elsewhere on the board
/Components/LED_9: R19.1; also elsewhere on the board
/EN: C4.1, R20.2, SW7.2; also elsewhere on the board
GND: BZ1.2 (-), C4.2, D1.1 (K), D2.1 (K), D3.1 (K), D4.1 (K), D5.1 (K), D6.1 (K), D7.1 (K), D8.1 (K), D9.1 (K), D10.1 (K), R4.2, R5.2, R6.2, R7.2, SW7.1; also elsewhere on the board
unnamed: D1.2 (A), R10.2
unnamed: D2.2 (A), R11.2
unnamed: D3.2 (A), R12.2
unnamed: D4.2 (A), R13.2
unnamed: D5.2 (A), R14.2
unnamed: D6.2 (A), R15.2
unnamed: D7.2 (A), R16.2
unnamed: D8.2 (A), R17.2
unnamed: D9.2 (A), R18.2
unnamed: D10.2 (A), R19.2

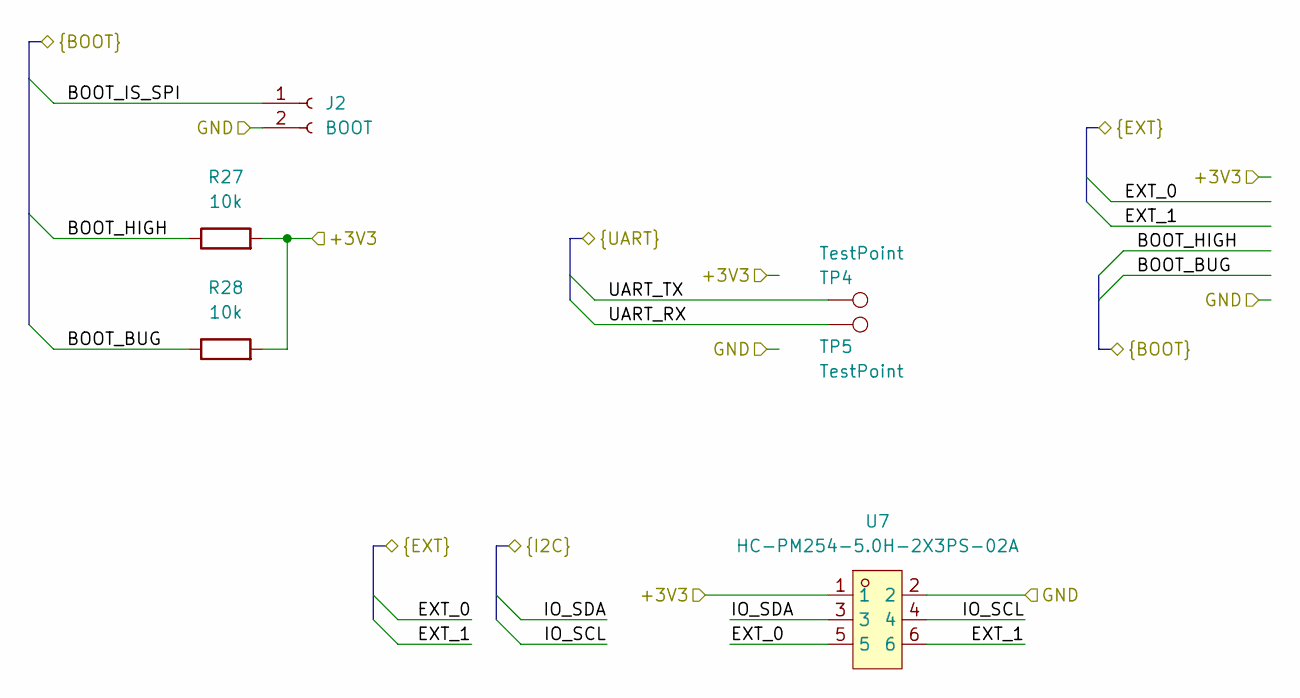
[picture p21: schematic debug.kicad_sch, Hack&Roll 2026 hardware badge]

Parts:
J2: BOOT; PinSocket_1x02_P2.54mm_Vertical
R27, R28: 10k; R_0805_2012Metric; LCSC Part # C2930231
TP4, TP5: TestPoint; TestPoint_Pad_2.5x2.5mm
U7: HC-PM254-5.0H-2X3PS-02A; CONN-SMD_HC-PM254-5.0H-2X3PS-02A; LCSC Part C42163131

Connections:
+3V3: R27.2, R28.2, U7.1; also elsewhere on the board
/Debug connectors/BOOT_BUG: R28.1; also elsewhere on the board
/Debug connectors/BOOT_HIGH: R27.1; also elsewhere on the board
/Debug connectors/BOOT_IS_SPI: J2.1; also elsewhere on the board
/Debug connectors/EXT_0: U7.5; also elsewhere on the board
/Debug connectors/EXT_1: U7.6; also elsewhere on the board
/Debug connectors/UART_RX: TP5.1; also elsewhere on the board
/Debug connectors/UART_TX: TP4.1; also elsewhere on the board
/Microcontroller unit/IO_SCL: U7.4; also elsewhere on the board
/Microcontroller unit/IO_SDA: U7.3; also elsewhere on the board
GND: J2.2, U7.2; also elsewhere on the board

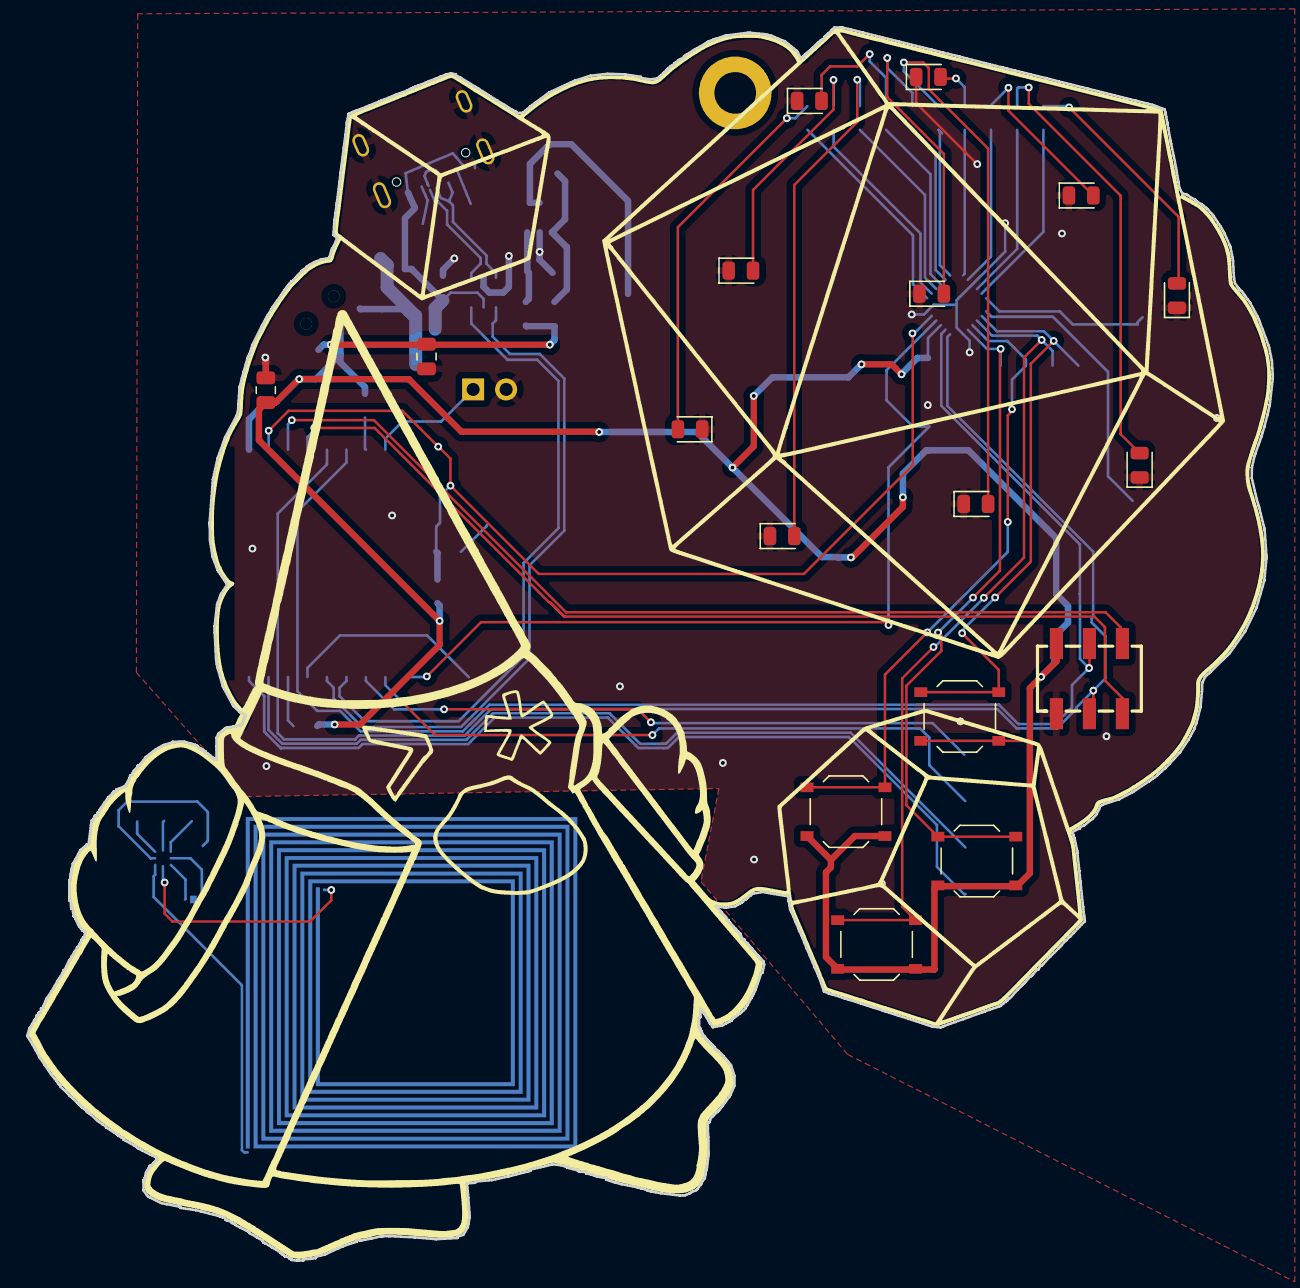
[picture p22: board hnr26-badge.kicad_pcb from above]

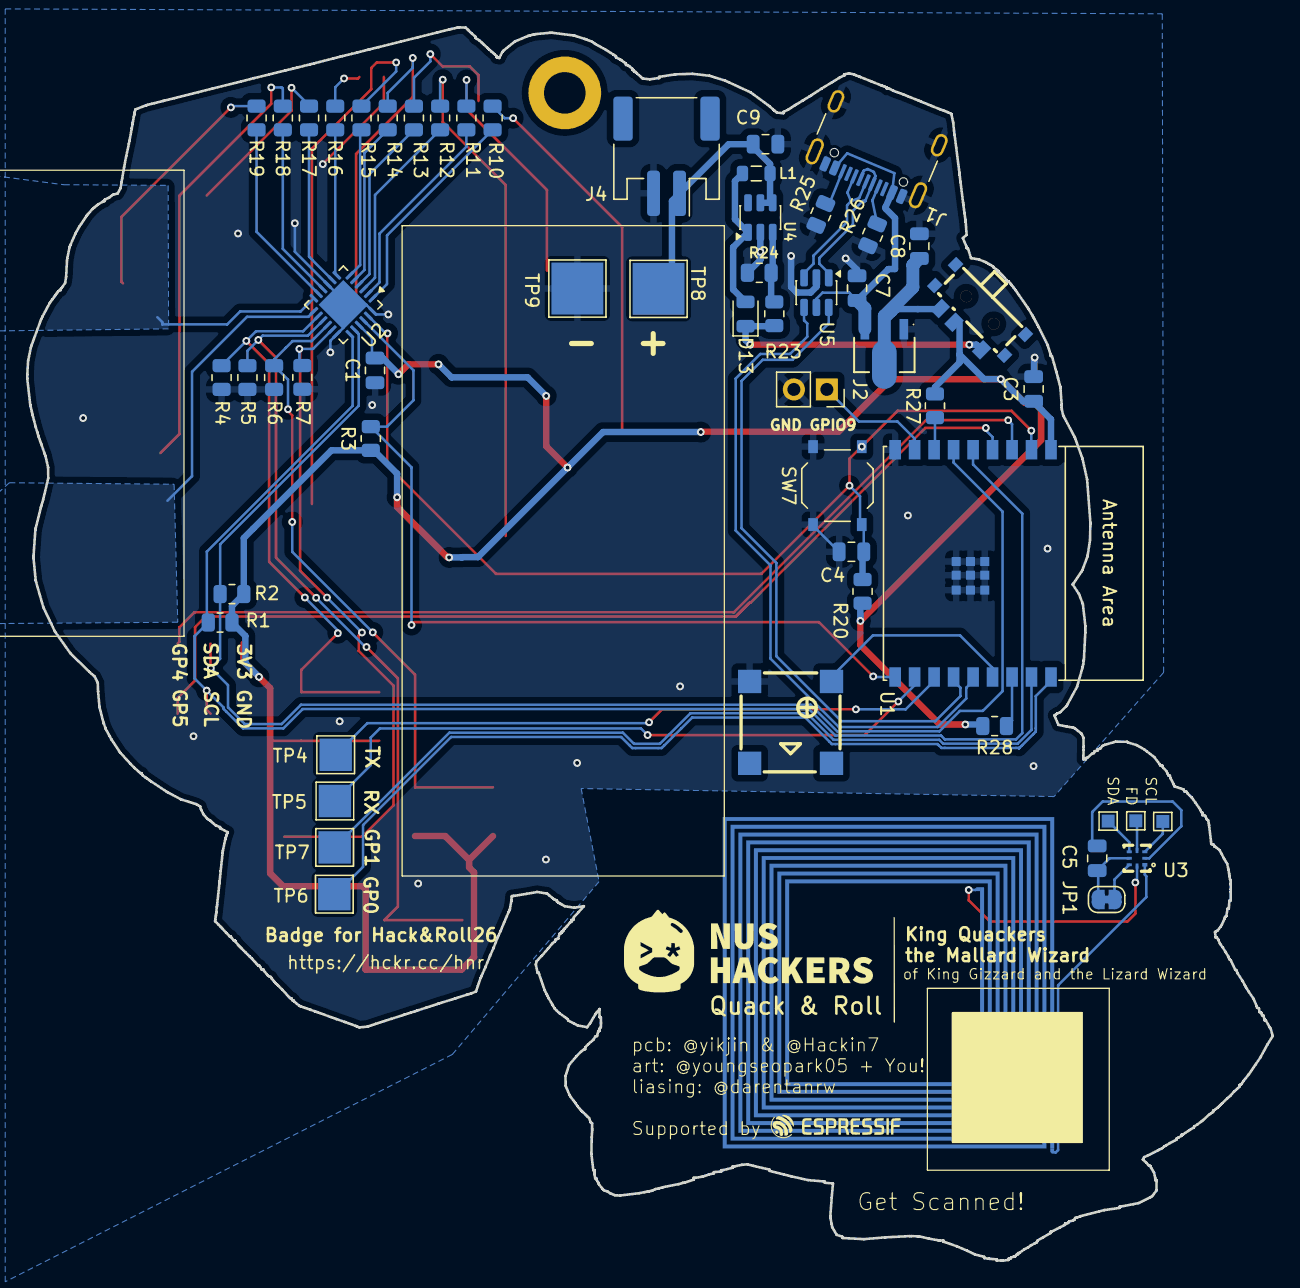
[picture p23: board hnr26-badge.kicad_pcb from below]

Board: 2 copper layers, 95.9 x 95.0 mm, 74 parts (56 on the bottom side), 60 nets.

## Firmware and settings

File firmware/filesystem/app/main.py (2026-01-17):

from hardware.main import Hardware
from hardware.ble_comms import BLETextClient, BLETextServer
import app.led_blinks as led_blinks
import os
import machine

app_unlocks = []
def load_unlocks():
    try:
        global app_unlocks
        app_unlocks.clear()
        for i in range(100):
            exec(f"import app.unlock{i} as unlock")
            app_unlocks.append(unlock)
    except Exception as e:
        print("Limited Unlocks:", e)
load_unlocks()


import random
import asyncio
import time
import machine

rtttl_songs = [
    'rap:d=8,o=6,b=180:2d4,f4,a4,4d5,d,d,c,a5,d,d,c,d,c,d,c,a5,d,d,a5,d,c,d,c,a5,d,2d4,f4,a4,4d5,f5,d5,a4,f4,2d#4,d,d,c,d,c,d,c,a5,d,d,c,d,c,d,c,a5,d',
    'BackInBlack:d=4,o=6,b=180:e,p,p,d,d,p,p,a5,a5,p,p,p,p,8g,8e,8d,8b5,8a5,8a5,8g5,e,p,p,d,d,p,p,a5,a5,p,8b5,g5,8b5,a5,8b5,a#5,8b5,g5',
    'CuttingCrewDiedInYourArms:d=8,o=6,b=125:f#,f#,f#,f#,f#,f#,f#,f#,a,a,a,g,g,g,f#,f#,e,e,e,e,e,e,e,e,f#,f#,f#,c#,c#,c#,d,d,2f#.,e,f#,4g.,g,4f#.,d,1e,f#,e,f#,e,f#,e,d,d,2b5',
    'Quack1:d=16,o=6,b=63:8b,f,e,p,p,32e,32e,32e,32f,32e,p,p,32e,32e,32f,32e,32f,32e,p,32g5,32g5,32g5,32f#5,32e5,e5,32e5,32g5,32g5,32g5,32g5,32f#5,32e5,p,b,16b,b,8b',
    'EuropeTheFinalCountdown:d=4,o=5,b=200:p,p,8c#6.,16b,2c#6,2f#,p,p,p,8d6.,16c#6,4d6,4c#6,2b,p,p,p,8d6.,16c#6,2d6,2f#,p,p,p,8b.,16a,4b,4a,4g#,4b,2a',
    'QueenDontStopMeNow:d=8,o=6,b=125:g,g,a#5,a#5,a#5,4c,4d,p,e,e,e,4f,4g,p,4a5,4f5,f5,a5,c,f,2e,p,c,a5,4g5,4f5,4p,a5,g5,f5,4g5,g5,g5,a5,4a#5,1c', 
    'LastChristmas:d=8,o=6,b=112:4e,e,4e,4d,a5,e,e,f#,2d,a5,e,e,4f#,4d.,d,c#,d,c#,2b5,4p,4f#,f#,4e,4p,b5,f#,g,f#,4e,4p,d,c#,c#,c#,4c#,4d,4c#,4a5,2a5,4p',
    'jlohasbeeps:d=4,o=6,b=200:8f#,8f#,8f#,4e,4e,4a5,4a,e,8a5,8a5,8f#,8f#,8f#,8a5,f#,8e,8e',
    ('QZKago:d=4,o=5,b=125:8c,8d,8d#,8g4,8f#4,16g4,8g#4,8d#,16d#,8d,8d#,' +
          '8f,8d#,8d,16d#,8d,8c,16b4,8c,8d,'+
          '8d#,8g#4,16g4,8g#4,8g4,16d#,16d,16d#,8d,8c,8b4,8a4,8b4,c'+
          '8c,8d,8d#,8g4,8f#4,16g4,8g#4,8d#,16d#,8d,8d#,' +
          '8f,8d#,8d,16d#,8d,16c,16c,4g,'+
          '8d#,8g#4,16g4,8g#4,8g4,16g4,16f#4,16g4,16.,16g,16f#,16g,16.,'+
          '16f,16d#,16d,16c,16d,16d#,16f,16b4,4c'),
    'mirrortune:d=16,o=5,b=160:32c6,32p,c6,a#5,c6,p,a#5,p,c#6,p,c6,a#5,p,c6,p,a#5,p,32f5,32p,f5,g5,p,f5,p,d5,p,c5,p,a#4,p,c5,p,g4,f4,8p,a#5,c6,p,a#5,p,c#6,p,c6,a#5,p,c6,p,a#5,p,f5,f#5,g5,p,32g6,32p,32g6,32p,32g6,32p,32g6,32p,32g6,32p,32g6,32p,g6,f6,p,g6,4p,a#5,c6,p,a#5,p,c#6,p,c6,a#5,p,c6,p,a#5,p,32f5,32p,f5,g5,p,f5,p,d5,p,c5,p,a#4,p,c5,p,g4,f4,8p,a#5,c6,p,a#5,p,c#6,p,c6,a#5,p,c6,p,a#5,p,f5,f#5,g5,p,f5,f#5,g5,p,f5,f#5,4g5,8p'
]

class MusicException(Exception):
    pass

# Programs
class ModeManager:
    def __init__(self, hw):
        self.hw = hw
        
        self.mode = 0;
        self.num_modes = 6 + len(app_unlocks) + 1
        self.current_task = None
        
        # Program State
        self.input_states = [0,0,0,0,0,0]
        
        #self.hw.aw.pad_config(1) # a as an input
        #self.hw.aw.pad_write(1, 1)
        
    ### Helper Tasks ##############################
    async def state_inc(self):
        self.mode = (self.mode + 1) % self.num_modes
        await self.mode_reload()
    
    async def mode_reload(self):
        if self.current_task is not None:
            self.current_task.cancel()
            self.current_task = None
            
        if self.mode == 0:
            self.current_task = asyncio.create_task(led_blinks.blink_random(self.hw))
        elif self.mode == 1:
            self.current_task = asyncio.create_task(led_blinks.cycle(self.hw))
        elif self.mode == 2:
            self.current_task = asyncio.create_task(led_blinks.cycle_down(self.hw))
        elif self.mode == 3:
            self.current_task = asyncio.create_task(self.led_button_select())
        elif self.mode == 4:
            self.current_task = asyncio.create_task(led_blinks.smiley_face(self.hw))
        elif self.mode == 5:
            self.current_task = asyncio.create_task(led_blinks.flat_face(self.hw))
        elif self.mode == self.num_modes - 1:
            self.current_task = asyncio.create_task(led_blinks.all_on(self.hw))
            try:
                await self.bluetooth_mode()
            except Exception as e:
                print("bluetooth fail")
                await led_blinks.cross(self.hw, 2000)
                machine.reset()
        elif self.mode >= 6:
            try:
                self.current_task = asyncio.create_task(app_unlocks[self.mode-6].unlock(self.hw))
            except AttributeError as e:
                print("remove invalid module")
                os.remove(f"/app/unlock{self.mode-6}.py")
                #await led_blinks.cross(self.hw, 2000)
                await self.state_inc()
        time.sleep(0.5)
            
    async def read_inputs(self):
        while True:
            self.input_states = hw.read_buttons()
            self.input_states += [hw.aw.pad_read_A()]
            await asyncio.sleep(0.1) # Polling Rate
        
    async def bluetooth_mode(self):
        if self.current_task is not None:
            self.current_task.cancel()
            self.current_task = None
        
        hw.write_leds([1]*10)
        
        while True:
            button_val_list = hw.read_buttons()
            button_down_pressed = button_val_list[1] # Down bitton
            if (button_down_pressed):
                break
            await asyncio.sleep(0.02)
        
        hw.write_leds([0]*10)
        
        client = BLETextClient()
        value = await client.run()
        print(value)
        
        if value is None or value == "":
            await led_blinks.cross(self.hw, 2000)
            machine.reset()
            return
        
        filename = f"/app/unlock{len(app_unlocks)}.py"
        with open(filename, "w") as f:
            print("Writing to file:", filename)
            f.write(value)
        await led_blinks.tick(self.hw, 2000)
        machine.reset()
        
    ### Async Programs/ Functions #####################
    async def led_button_select(self):
        leds = [1,0,0,0,0,0,0,0,0,0]
        
        hw.write_leds(leds)
        while True:
            btns = self.input_states
            if btns[3]:
                leds = leds[1:] + [leds[0]]
                hw.write_leds(leds)
            elif btns[2]:
                leds = [leds[-1]] + leds[:-1]
                hw.write_leds(leds)
            ### Music Playing
            elif btns[1]:
                state = leds.index(1)
                task = hw.get_rtttl_task(rtttl_songs[state%len(rtttl_songs)])
                asyncio.run(task())
                raise MusicException() # Trick to avoid crashing
            await asyncio.sleep(0.2)

    ### Main ##########################################
    async def main(self):
        asyncio.create_task(self.mode_reload())
        asyncio.create_task(self.read_inputs())
        
        while True:
            #asyncio.run(self.read_inputs())
            if self.input_states[0]: # Up Button
                asyncio.create_task(self.state_inc())
            await asyncio.sleep(0.2)
        
        
hw = Hardware()
mm = ModeManager(hw)

try:
    # Start the event loop and run the main coroutine
    while True:
        try:
            asyncio.run(mm.main())
        except MusicException:
            pass
except KeyboardInterrupt:
    pass # Handle manual interruption
finally:
    # Clear retained state in the event loop for subsequent runs
    asyncio.new_event_loop()

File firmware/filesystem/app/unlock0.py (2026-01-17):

import asyncio
import random
import time
from hardware.ble_comms import *

async def led_pwm_duration(hw, leds, duration, always=False):
    ticks = time.ticks_ms()
    while always or time.ticks_ms() - ticks < duration:
        time.sleep(0.00001)
        hw.write_leds([0]*10)
        await asyncio.sleep(0.02)
        hw.write_leds(leds) 



async def cycle_down(hw, val):
    leds = [1,0,0,0,0,0,0,0,0,0]
    for i in range(val):
        hw.write_leds(leds)
        old = leds.index(1)   # find current 1
        new = (len(leds) + old - 1) % len(leds)
        leds[old] = 0
        leds[new] = 1
        hw.buzzer_on(440)
        await asyncio.sleep(0.05)
        hw.buzzer_off()
        await asyncio.sleep(0.05)
        

async def cycle_up(hw, val):
    leds = [1,0,0,0,0,0,0,0,0,0]
    for i in range(val):
        hw.write_leds(leds)
        old = leds.index(1)   # find current 1
        new = (len(leds) + old + 1) % len(leds)
        leds[old] = 0
        leds[new] = 1
        hw.buzzer_on(440)
        await asyncio.sleep(0.05)
        hw.buzzer_off()
        await asyncio.sleep(0.05)
        
async def dice_roll(hw, val, start):
    print("Pattern to Play:", val)
    all_on = [1,1,1,1,1,1,1,1,1,1]
    hw.write_leds(all_on)
    
    mode = val[0]
    curr = int(val[1:])
    
    win = (
        (start and int(val[1:].strip()) % 2 == 0) or
        (not start and int(val[1:].strip()) % 2 == 1)
    )
    
    if mode == "A":
        while curr > 10:
            print(curr)
            await cycle_down(hw, 10)
            curr -= 10
        await cycle_down(hw, curr)
    elif mode == "B":
        while curr > 10:
            print(curr)
            await cycle_up(hw, 10)
            curr -= 10
        await cycle_up(hw, curr)
    elif mode == "C":
        curr = val[1:]
        leds = [1,0,0,0,0,0,0,0,0,0]
        for c in curr:
            hw.write_leds(leds)
            pos = int(c)
            old = leds.index(1)   # find current 1
            new = pos
            leds[old] = 0
            leds[new] = 1
            hw.buzzer_on(440)
            await asyncio.sleep(0.05)
            hw.buzzer_off()
            await asyncio.sleep(0.05)
    
    if (not win):
        hw.write_leds([0]*10)
    
    await asyncio.sleep(5)
    
    
def random_generate_pattern(mode_int=None):    
    modes = "ABC"
    if mode_int is None: mode_int = random.randint(0,len(modes)-1)
    pattern = modes[mode_int]

    if pattern == "C":
        for i in range(random.randint(25,75)):
            pattern += str(random.randint(0,9))
    else:
        pattern += str(random.randint(25,75))
    
    return pattern


async def unlock(hw):
    while True:
        leds = [0,0,0,0,1,1,1,1,1,1]
        
        while True:
            time.sleep(0.00001)
            hw.write_leds([0]*10)
            button_val_list = hw.read_buttons()
            button_down_pressed = button_val_list[1] # Down bitton
            if (button_val_list[1]): # Bluetooth mode
                break
            elif (button_val_list[2] & button_val_list[3]):
                TEXT = random_generate_pattern(2)
                print(f"dice: {TEXT}")
                await dice_roll(hw, TEXT, 1)
            elif (button_val_list[2]):
                TEXT = random_generate_pattern(0)
                print(f"dice: {TEXT}")
                await dice_roll(hw, TEXT, 1)
            elif (button_val_list[3]):
                TEXT = random_generate_pattern(1)
                print(f"dice: {TEXT}")
                await dice_roll(hw, TEXT, 1)
                
            await asyncio.sleep(0.02)
            hw.write_leds(leds)
            
        leds = [0,0,0,0,1,1,1,1,1,1]
        hw.write_leds(leds)
        time.sleep(random.random())
        
        client = BLETextClient(target_name="dice", scan_time_ms=1000)
        value = await client.run()
        print(value)
        
        if value is not None:
            hw.buzzer_on(329)
            await dice_roll(hw, value.decode(), 0)
            continue
        
        TEXT = random_generate_pattern()
        print(f"dice: {TEXT}")
        server = BLETextServer(name="dice",text=TEXT)
        await server.run()
        
        # after downloading
        await dice_roll(hw, TEXT, 1)

if __name__ == "__main__":
    from hardware.main import Hardware
    hw = Hardware()
    asyncio.run(unlock(hw))
